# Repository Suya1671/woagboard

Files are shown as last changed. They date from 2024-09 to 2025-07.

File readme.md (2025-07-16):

# Woagboard: Bisexual egg edition
_name chosen by popular vote._

Woagboard

**ROUND 3** This is the third hardware revision of the Woagboard keyboard. It's a 5x3 split ergonomic keyboard with 3 thumb keys on each half (36 keys total), inspired by the [TOTEM](https://github.com/GEIGEIGEIST/TOTEM).

I made this keyboard for myself, and to learn PCB design in the process. With the newest iteration, I've gotten into case design (Actually properly learning CAD for once), way more annoying part selection processes, and overall a chaotic time.

# Features

Woagboard with the case opened

- 36 Keys
  - 5x3 matrix, with 3 thumb keys on each half
  - Splayed, column-staggered, ergonomic design
- Wireless, with generous space to fit a battery
  - 400mAh should last you a month
- On-board MCU
  - Nordic nRF52840, for BLE and USB-C connectivity
- Chaotic silkscreen printing
- Optional nice!view display mounting point
- RMK and ZMK firmware support

## The case
Woagboard Case

The case is designed to be 3D printed, with a focus on being thin, minimalistic, and clean. It features cutouts for all the necessary ports and buttons, and has a dedicated space for the nice!view display on the left half.
It also features cutouts for [Tenting Feet](https://www.aliexpress.com/item/1005005605228469.html) that make the keyboard way more comfy to use.

## The PCB

Woagboard PCB

Silly, chaotic, yet somehow functional. The PCB is as small as the layout allows it to be, featuring an on-board Ebyte E73-2G4M08S1C module for wireless connectivity (Powered by the Nordic nRF52840), a BQ24075RGT battery charger (Which allows you to charge the keyboard while it's running. Such a revolutionary feature), and a 32.768kHz crystal for deep sleep functionality.

It also has really chaotic silkscreening. We stay silly.

Woagboard PCB Silkscreen

### Schematic

Woagboard Schematic
:3

# BOM
This is the Bill of Materials (BOM) for 1 Woagboard (2 halves). This is why certain quanitites are doubled, as the board is two halves using the same PCB and components.
| Component | Designator on PCB/Usage | Supplier | Supplier URL | Quantity |
| --- | --- | --- | --- | --- |
| Woagboard PCB | Placed in case | JLCPCB | See pcb/jlcpcb for production files | 2 |
| Ebyte E73-2G4M08S1C MCU* | U1 | LCSC | <https://lcsc.com/product-detail/C356849.html> | 2 |
| TI BQ24075RGT Battery Charger | U2 | LCSC | <https://lcsc.com/product-detail/C15464.html> | 2 |
| Onsemi SRV05-4 ESD Protection | U3 | LCSC | <https://lcsc.com/product-detail/C2836319.html> | 2 |
| Korean Hroparts Elec TYPE-C-31-M-12 | J1 | LCSC | <https://lcsc.com/product-detail/C165948.html> | 2 |
| 1x6 Vertical Pin header | J2 | LCSC | <https://lcsc.com/product-detail/C706869.html> | 2 |
| Panasonic EVQ-P7C01P push button | PWR1,RST1 | LCSC | <https://lcsc.com/product-detail/C388883.html> | 4 |
| Yellow LED | LED1 | LCSC | <https://lcsc.com/product-detail/C2296.html> | 2 |
| Green LED | LED2 | LCSC | <https://lcsc.com/product-detail/C2297.html> | 2 |
| 4.7uF Capacitor | C2,C3,C4,C5 | LCSC | <https://lcsc.com/product-detail/C23733.html> | 8 |
| 1uF Capacitor | C1,C6 | LCSC | <https://lcsc.com/product-detail/C52923.html> | 4 |
| 18pF Capacitor | C7,C8 | LCSC | <https://lcsc.com/product-detail/C1549.html> | 4 |
| 47kΩ Resistor | R4 | LCSC | <https://lcsc.com/product-detail/C25792.html> | 2 |
| 10kΩ Resistor | R7 | LCSC | <https://lcsc.com/product-detail/C25744.html> | 2 |
| 5.1kΩ Resistor | R1,R2 | LCSC | <https://lcsc.com/product-detail/C25905.html> | 4 |
| 3.9kΩ Resistor | R6 | LCSC | <https://lcsc.com/product-detail/C23018.html> | 2 |
| 270Ω Resistor | R3,R5,R8 | LCSC | <https://lcsc.com/product-detail/C25867.html> | 6 |
| 750 mA fuse | F1 | LCSC | <https://lcsc.com/product-detail/C2687878.html> | 2 |
| 32.768kHz Crystal | Y1 | LCSC | <https://lcsc.com/product-detail/C32346.html> | 2 |
| Murata Electronics BLM15PX121SN1D Ferrite Bead | L1 | LCSC | <https://lcsc.com/product-detail/C88970.html> | 2 |
| 10uH Inductor | L2 | LCSC | <https://lcsc.com/product-detail/C223249.html> | 2 |
| Kailh PG1350 Choc Hotswap Sockets | SW1-SW18 | AliExpress** | <https://www.aliexpress.com/item/1005004290562374.html> | 30 x 2 (36 used) |
| Woagboard Case | Surrounds PCB. Connected Via M2 screws | 3D Printed | See case for models | 1x Left, 1x Right |
| M2x10 Countersunk Screws | H1 (Mounting Point) | JKM | <https://jkm.co.za/product/m2x10-csk-galv-m-screw-bos/> | 2 |
| M2x12 Countersunk Screws | H2, H3 (Mounting Points) | JKM | <https://jkm.co.za/product/m2x12-csk-galv-m-screw-bos/> | 4 |
| M2 Brass Heat inserts | H1, H2, H3 (Mounting Points) | AliExpress | <https://www.aliexpress.com/item/32890237459.html> | 50 x 1 (6 M2 inserts used) |
| Laptop Tenting Feet | Attached to case | AliExpress** | <https://www.aliexpress.com/item/1005005605228469.html> | 2 x 2 |
| Choc switches | SW1-SW18 (Connected via hotswap) | AliExpress | <https://www.aliexpress.com/item/1005005883472162.html> | 30 x 2 (36 used) |
| Choc keycaps | SW1-SW18 (Connected via switch) | AliExpress | <https://www.aliexpress.com/item/1005004558099208.html> | 50 x 1 (36 used) |
| nice!view | J4 (Wired up with wires. nice!view placed in case) | Typeractive  | <https://typeractive.xyz/products/nice-view> | 1 |

Notes:

- \* Alternativelty, the Ebyte E73-2G4M08S1CX can be used for a UFL connector, requiring an external antenna. Both options annoyingly got moved to standard assembly only while I was making this design, increasing costs dramatically (~$60 -> ~$100). I've contacted JLCPCB about this, and hopefully I can get it back on economic assembly for anybody else trying to make this board.
- ** Typeractive also has these. If you're in the US, might be better to buy from them instead.
- I already have switches and keycaps, so I don't need to purchase them.
- I am not purchasing the nice!view for the fact that I'm out of budget if I do. Thanks JLCPCB.

# Copyright notice
The Woagboard is not affiliated with New Blood Interactive, Tour De Pizza, or any other IPs referenced on the design.
I just like ULTRAKILL, Pizza Tower, etc.

- Keycap model taken from https://www.thingiverse.com/thing:4564253 (CC BY-NC)
- Keyswitch model taken from https://github.com/kiswitch/kiswitch
- nice!view model taken from https://www.printables.com/model/1114611-niceview-oled/files (CC BY-NC)
- Neocats from https://volpeon.ink/emojis/neocat/ (CC-BY-NC-SA-4.0)
- Neofox from https://volpeon.ink/emojis/neofox/ (CC-BY-NC-SA-4.0)
- Neodog from https://git.gay/moonrabbits/neodog/src/branch/main/neodog/neodog.png (CC-BY-NC-SA-4.0)
- Neorat from https://emoji-repo.absturztau.be/repo/neorat.zip (CC-BY-NC-SA-4.0)
- Neobread from https://github.com/olivvybee/emojis/blob/main/neobread/neobread.svg (CC-BY-NC-SA-4.0)
- Neobot from https://github.com/SymTrkl/emoji/blob/main/webres/neobot/neobot.png (CC-BY-NC-SA-4.0)
- Monadic Cat's mask from https://www.catmonad.xyz/pfp.html (CC-BY-SA-4.0)

The board's actual license is the CERN Open Hardware License v1.2. See the [license file](./license.md) for more information.

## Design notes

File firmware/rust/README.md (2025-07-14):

# Woagboard Firmware: RMK

RMK is a feature-rich and easy-to-use keyboard firmware, which has VIAL support and is incredibly power efficient.

The default layout is the wobbler's personal layout, using dust and a bunch of fancy features.
I'll eventually probably maybe make the default QWERTY and less opinionated.

## uf2 support

If you’re using the Adafruit_nRF52_Bootloader (Recommended for the Woagboard), you’re in luck! This bootloader supports the .uf2 firmware format, which eliminates the need for a debugging probe to flash your firmware. RMK uses the `cargo-make` tool to generate .uf2 firmware, with the generation process defined in the `Makefile.toml`.

Follow these steps to generate and flash the .uf2 firmware with RMK:

1. Get `cargo-make` tool:
   ```shell
   cargo install --force cargo-make
   ```
2. Compile RMK and generates .uf2 firmware:
   ```shell
   cargo make uf2 --release
   ```
3. Flash
   - For each half:
    - Put your half into bootloader mode. This can be done by quickly double tapping the reset button.
    - A USB drive will appear on your computer under the name "WOAGBOARD".
    - Drag and drop the generated .uf2 firmware file onto the USB drive. The RMK firmware will be automatically flashed onto the Woagboard.

### Additional notes

RMK defaults to USB-priority mode if a USB cable is connected. After flashing, remember to disconnect the USB cable, or [switch to BLE-priority mode](https://rmk.rs/docs/features/wireless.html#multiple-profile-support) by pressing User7(Switch Output) key.

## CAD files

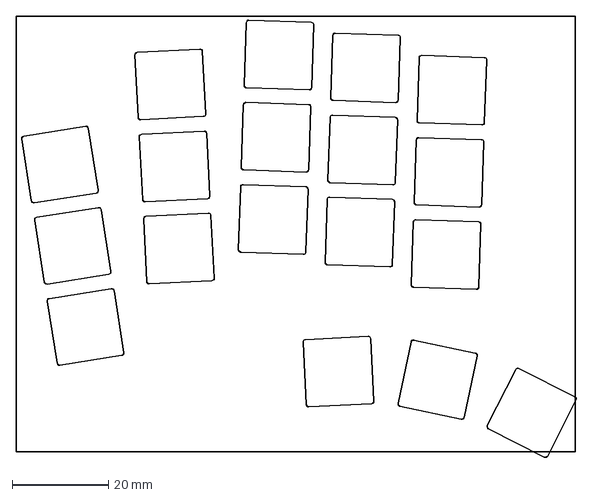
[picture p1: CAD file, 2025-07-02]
case/plate.dxf
116.2 x 91.6 mm

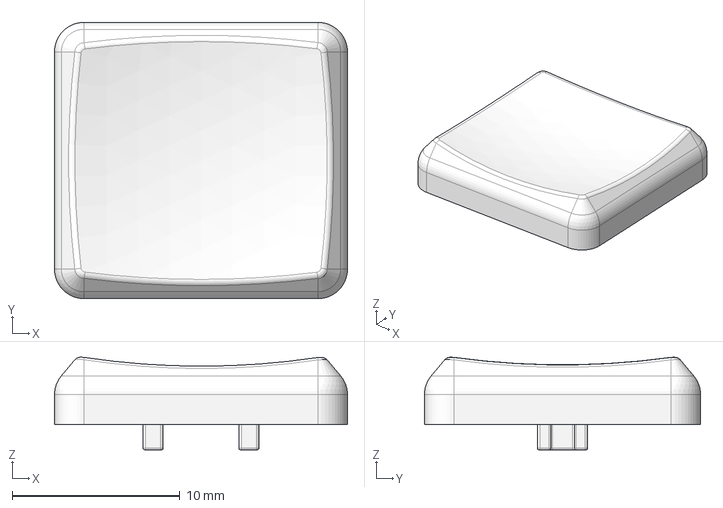
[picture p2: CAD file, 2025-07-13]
pcb/Models/MBK_Keycap_-_1u.step
17.4 x 16.4 x 5.52 mm

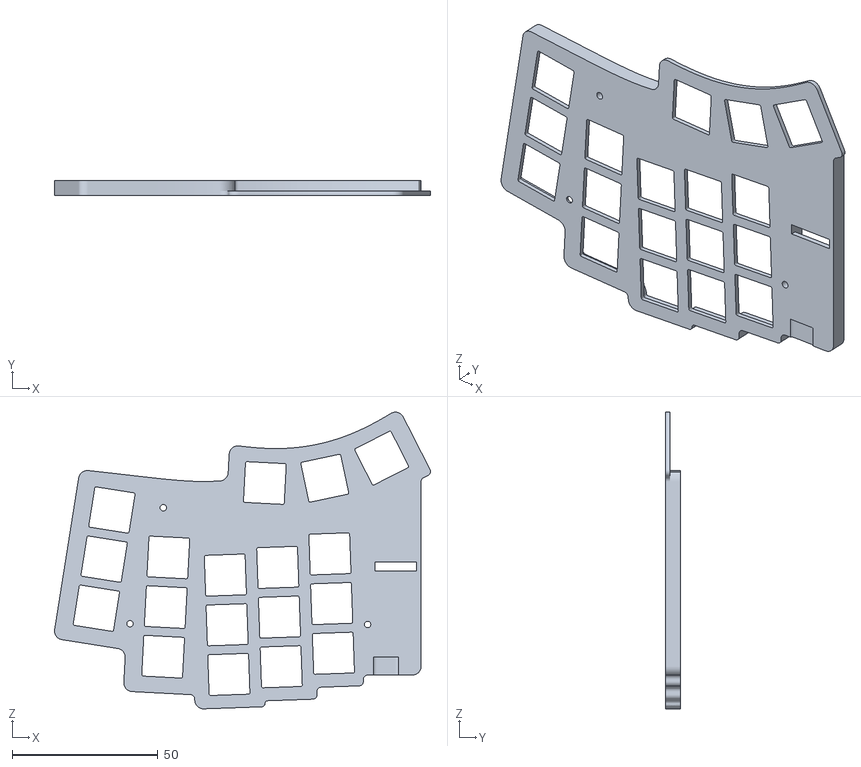
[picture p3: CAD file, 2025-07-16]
production/Top Left.stl
129.0 x 5.00 x 101.8

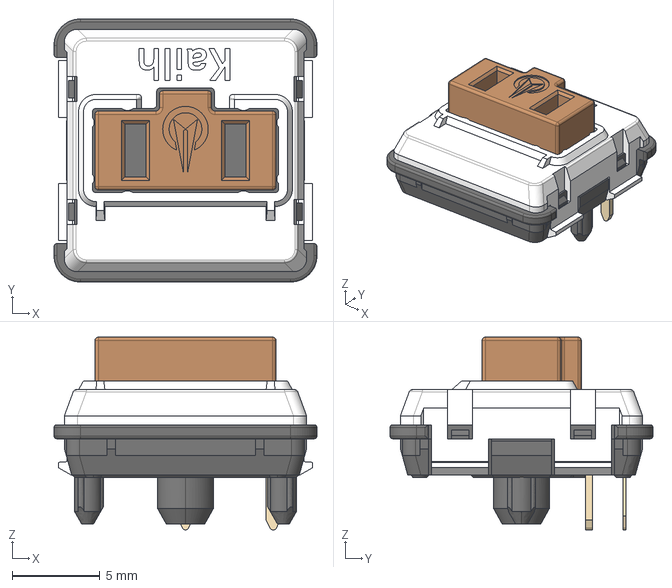
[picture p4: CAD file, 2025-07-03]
pcb/Models/SW_Kailh_Choc_V1.stp
15.0 x 15.0 x 11.0 mm

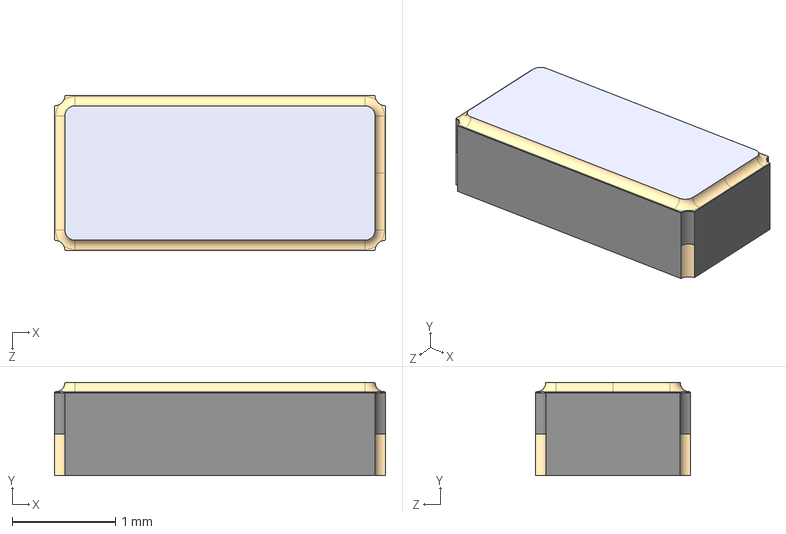
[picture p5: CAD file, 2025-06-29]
pcb/Models/Q13FC13500004.STEP
3.20 x 0.9 x 1.50 mm

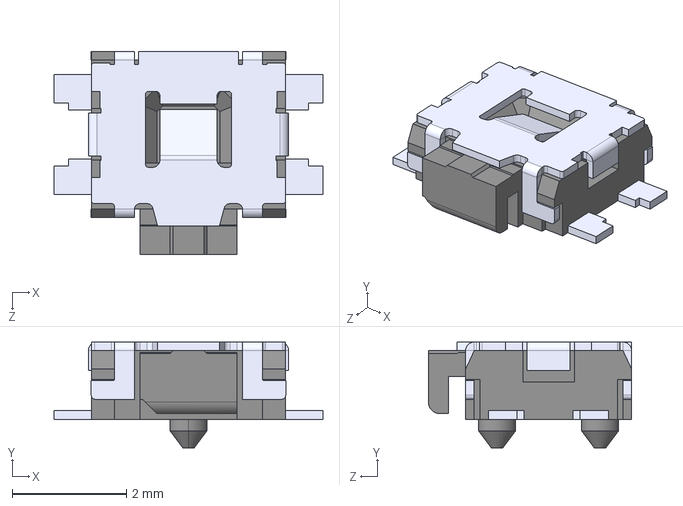
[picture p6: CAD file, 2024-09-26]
pcb/Models/EVQP7C01P--3DModel-STEP-269445.STEP
4.70 x 1.85 x 3.55 mm

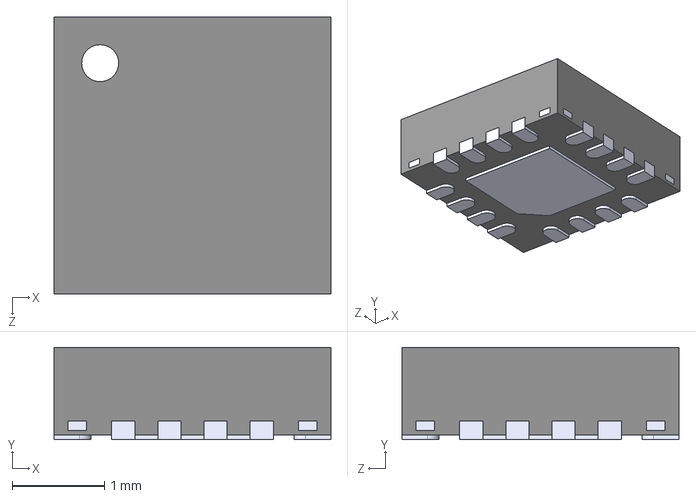
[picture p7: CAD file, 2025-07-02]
pcb/Models/BQ24075.STEP
3.00 x 1.00 x 3.00 mm

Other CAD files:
production/Top Right.stl

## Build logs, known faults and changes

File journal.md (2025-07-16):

---
title: "Woagboard V3"
author: "Suya"
description: "My woagboard keyboard idea combined with a modified version of the yeagpad's layout."
created_at: "2025-06-28"
---

**Total hours spent: ~50 hours**

# June 26th

I started working on getting the project setup. I removed the old files, updated the Ergogen code, and recreated the KiCAD project

Also, I use Ergogen to just [place the switches](https://github.com/adamws/kicad-kbplacer) on the PCB using a KiCAD. No actual PCB is generated by it.

## Schematic work

I'm mostly taking ideas and design from the amazing [ZMK Design guide](https://github.com/ebastler/zmk-designguide) and the work I've done for quiz-sys. I plan to re-use most of the components I did for the [Woagboard v0.2](https://github.com/suyashsurya/woagboard/tree/v0.2), but with everything completely re-done.

Fun thing for the BQ24075 is that I can just... Completely ignore the SYSOFF pin. ZMK has a soft-off mode that allows me to turn off and on the keyboard
through a button, so I'll be adding that to my design.

I decided to move a bunch of components in-line rather than putting them on a separate bit of the schematic, such as the low-power oscillator and DCCH inductor.
The design on the design guide confused me for the first time, since it didn't make sense to me. This makes it way clearer to my silly brain.

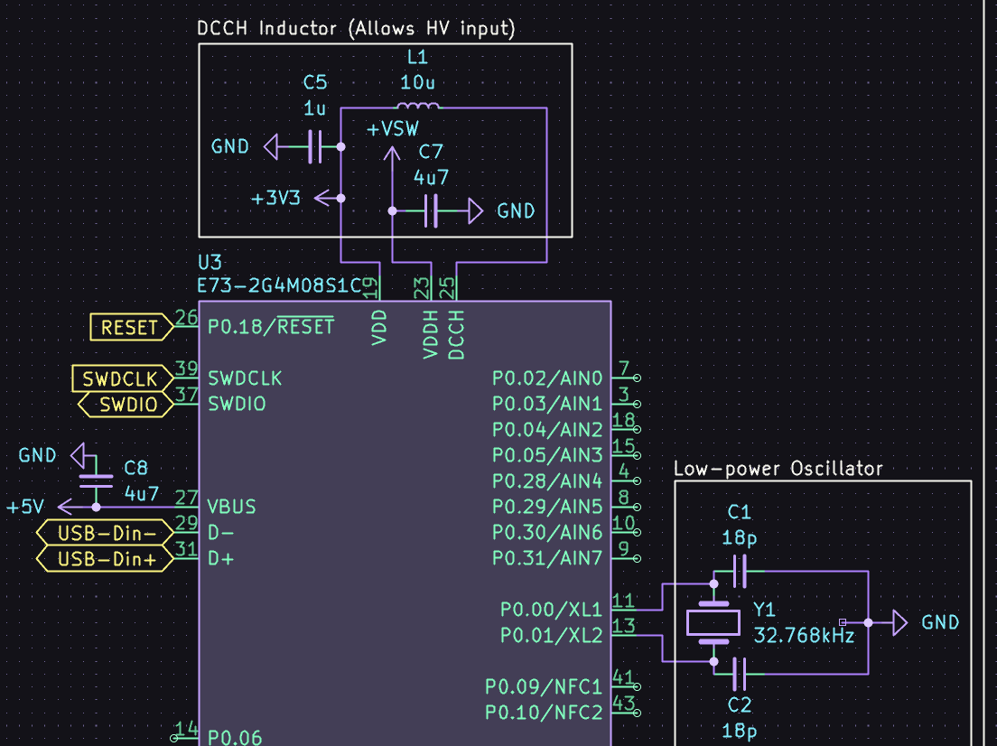
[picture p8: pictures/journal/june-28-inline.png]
A part of the woagboard's MCU schematic

_Huh. That's a lot clearer than the decoupling capacitors being like 50 spaces away._

Not sure how I feel about the DCCH loop, but it works for now.

Also for the first time ever: I filled out the info block
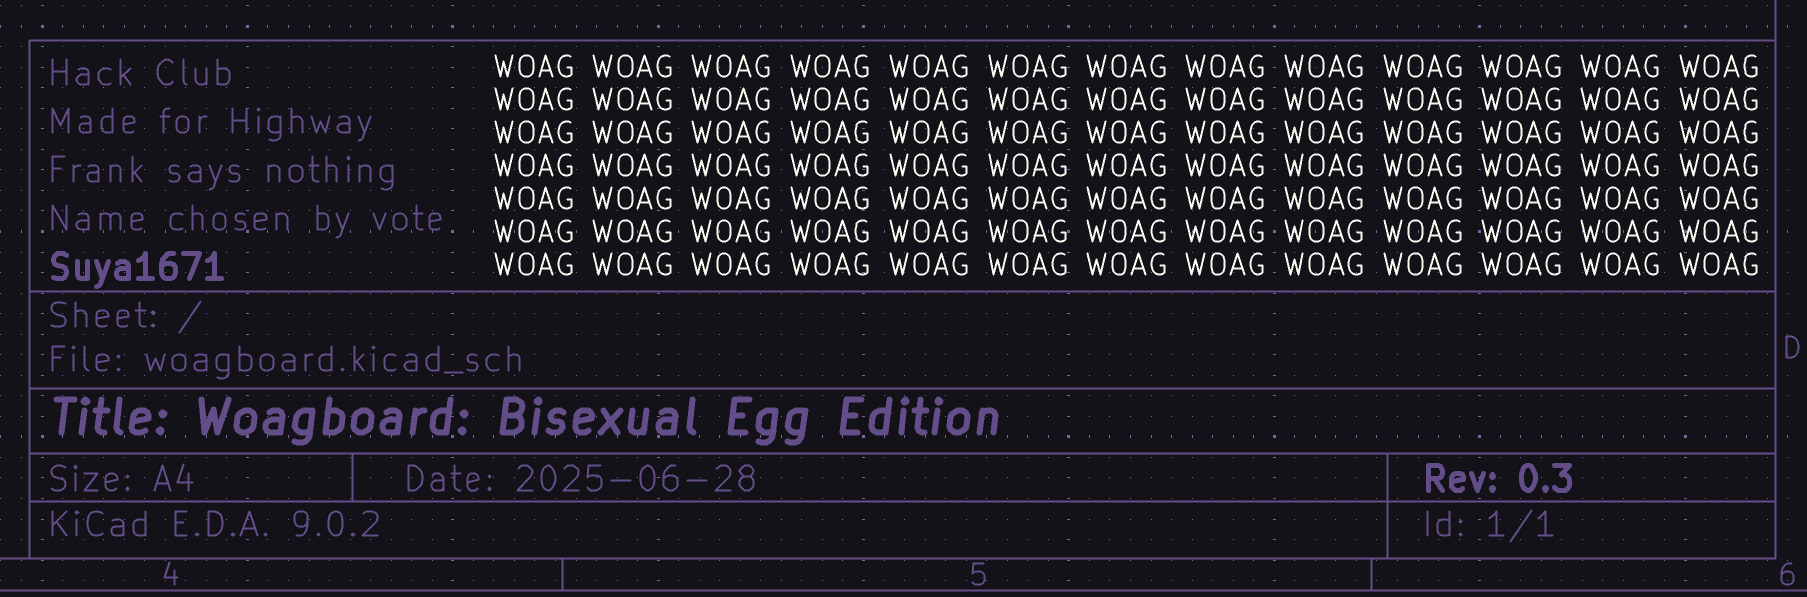
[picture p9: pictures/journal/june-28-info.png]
the woagboard's schematic's info block

_WOAG_

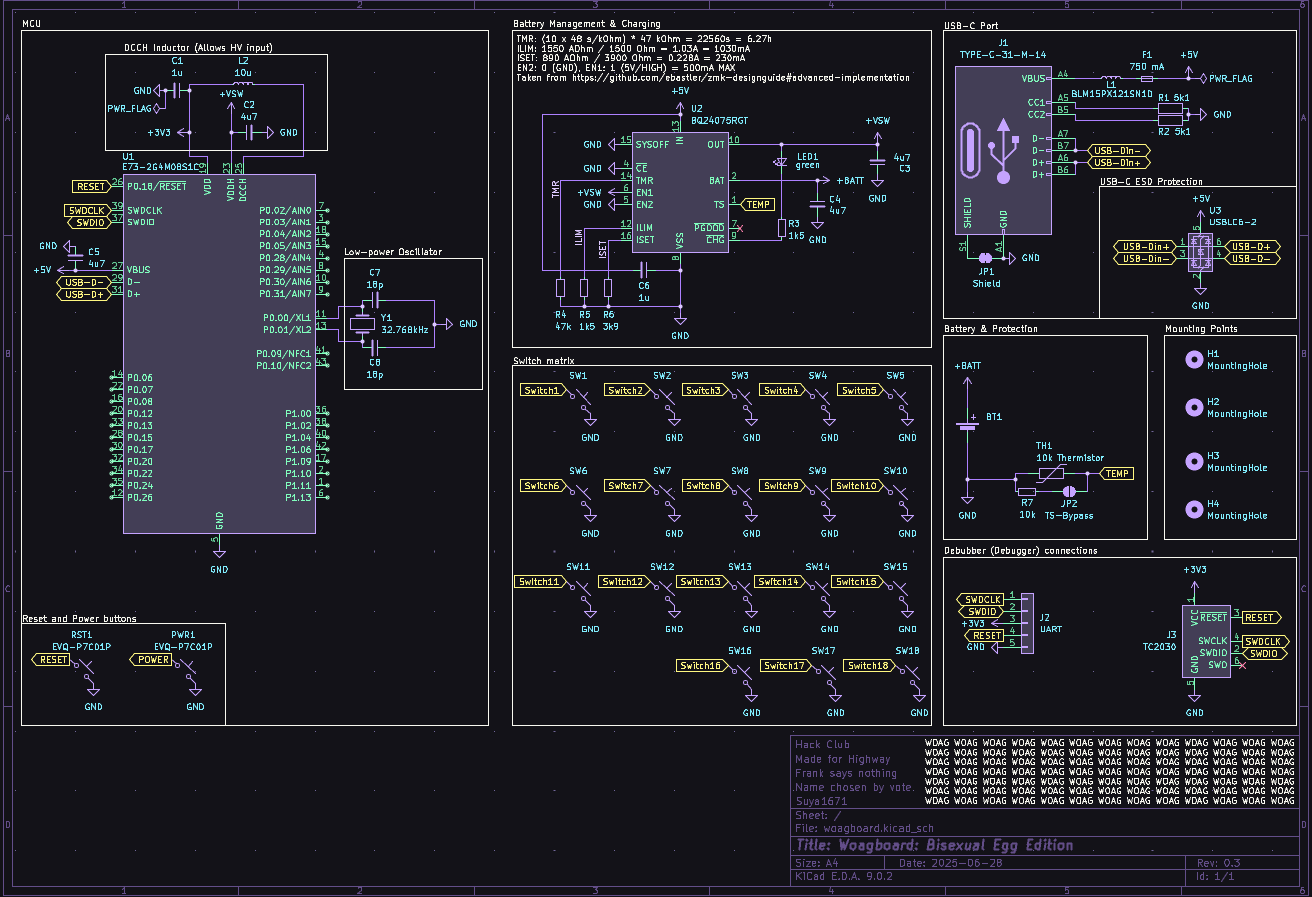
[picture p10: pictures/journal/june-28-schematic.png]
the woagboard's schematic

_I'm pretty proud of this ngl_

I might add ARGB later, depending on if I'm feeling up for the absolute routing nightmare that it is going to be

**Total time spent: 3 hours**

Next up: PCB footprints and board outline

# June 27th

Started early today at ~11:10. Worked for... the entire day.

Did a check over my schematic and started working on footprints. I redid my old Panasonic EVQP7C01P footprint and made a new crystal oscillator footprint.

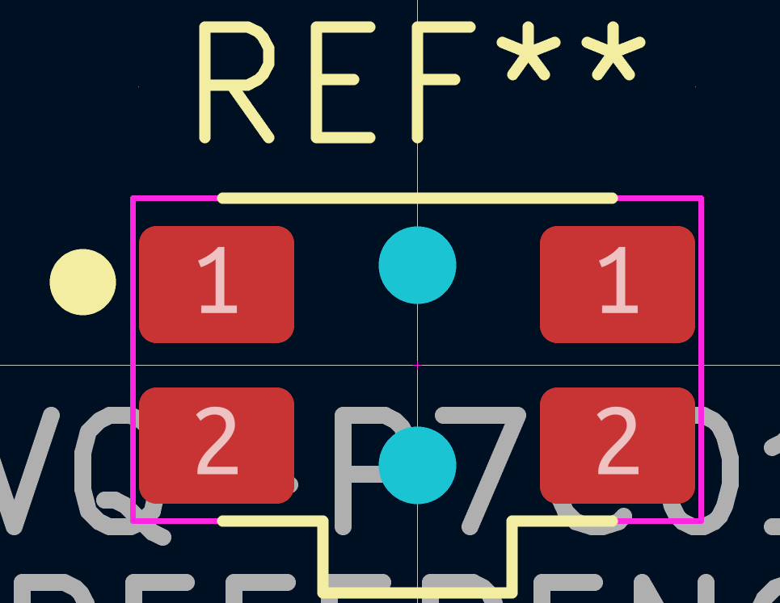
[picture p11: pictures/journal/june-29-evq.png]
EVQP7C01P footprint

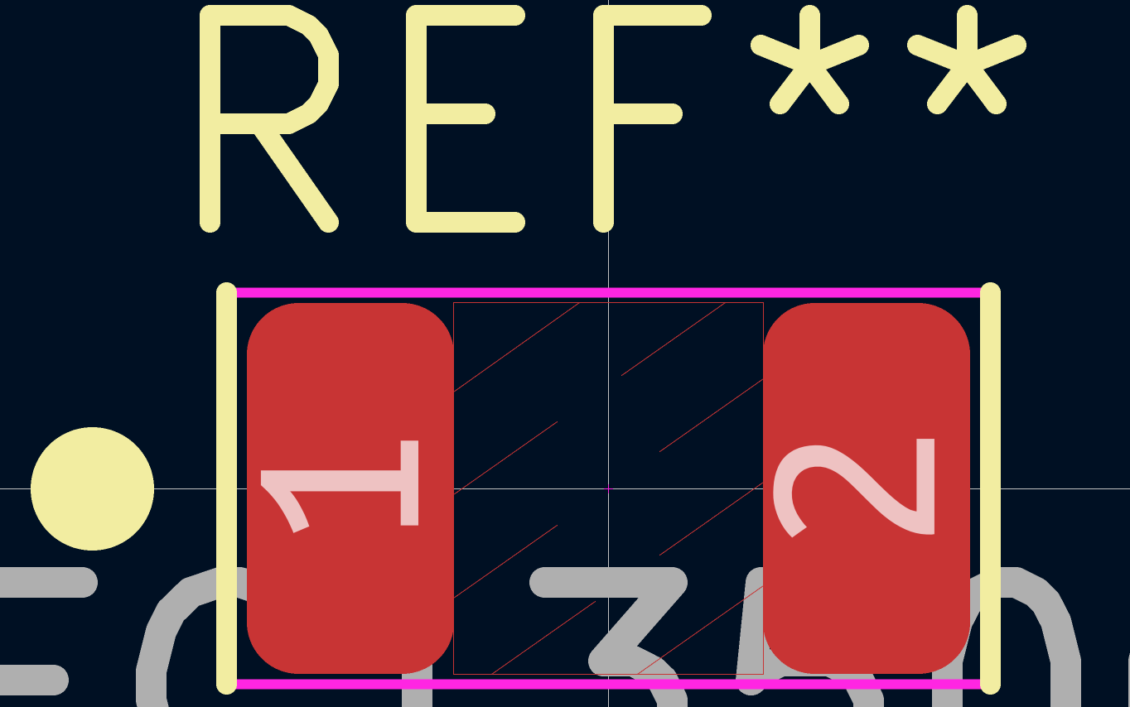
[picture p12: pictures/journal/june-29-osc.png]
Crystal Oscillator Footprint

_Algebra go brr_

I took my Choc V1 Reversible PCB footprint from the Yeagboard. I am not remaking that. It genuinely took me 2 days to get that working when I did it.
I might modify it to add ARGB, but I'm unsure, especially considering battery life implications

Anyways: I started off with this mess for the PCB:
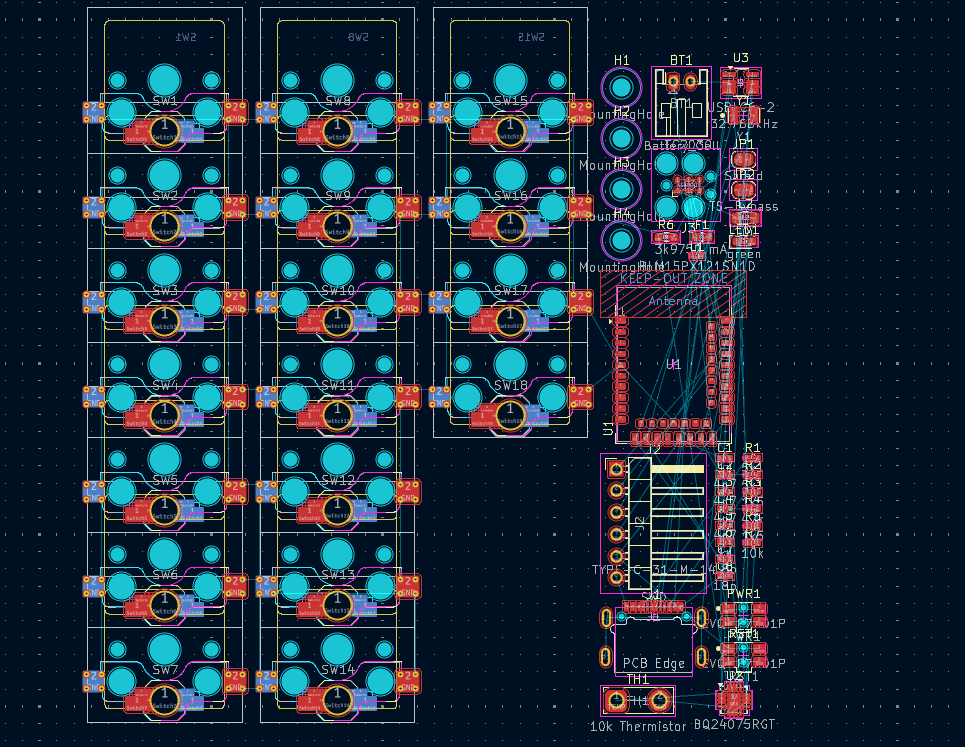
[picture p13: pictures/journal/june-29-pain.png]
A grid of all PCB components/footprints the woagboard uses

_Lettuce begin the train of pain_

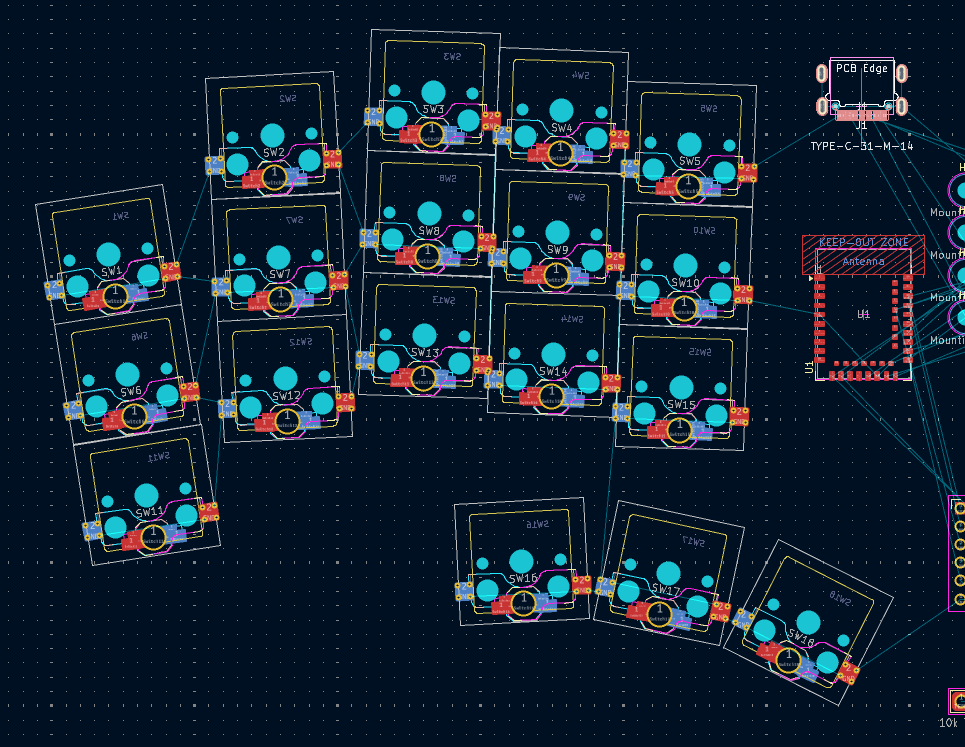
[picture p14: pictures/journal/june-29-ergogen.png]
Keys in the correct position

_...And this is the only reason I used ergogen_

I initially planned to have the MCU antenna face the right side of the board, but then I realised that, for my insanely tight routing plans, I would not have enough space.
Thus, compromise: the MCU faces downwards. This is going to be fun to route later.

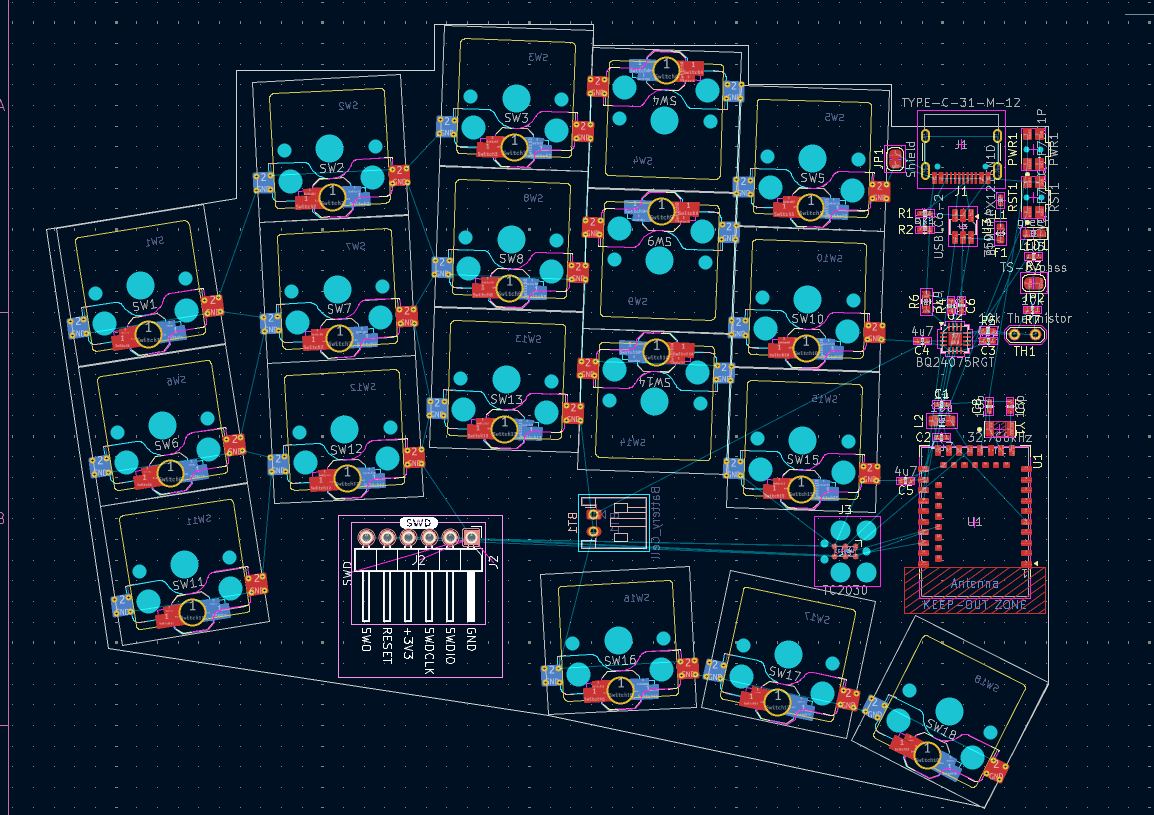
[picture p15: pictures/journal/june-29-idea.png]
WIP of final component positions

_Oh no..._

And then I kinda just... got into a flow. The world didn't exist. Just me, KiCAD, and a hell of a lot of routing to get done.
It is now... ~18:00 When I wrote this. It's been like 4 hours of continuous routing. I do not like routing because it feels
like you spent so much time but got nothing done. Bleh.

Anyways here's some fun things I've routed:

Tag Connect TC2030 "connector" (AKA just a bunch of pads and holes)
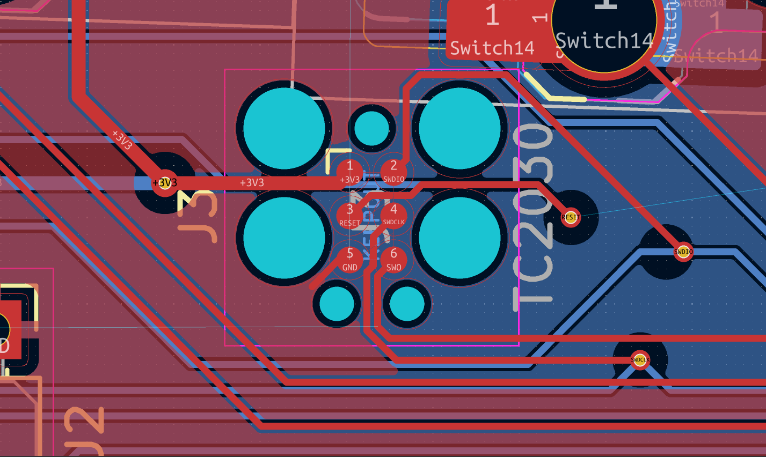
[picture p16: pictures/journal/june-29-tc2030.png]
Routed TC2030 connector

_Forgive me JLCPCB, for I have sinned_

The Nrf52840 DC/DC buck converter
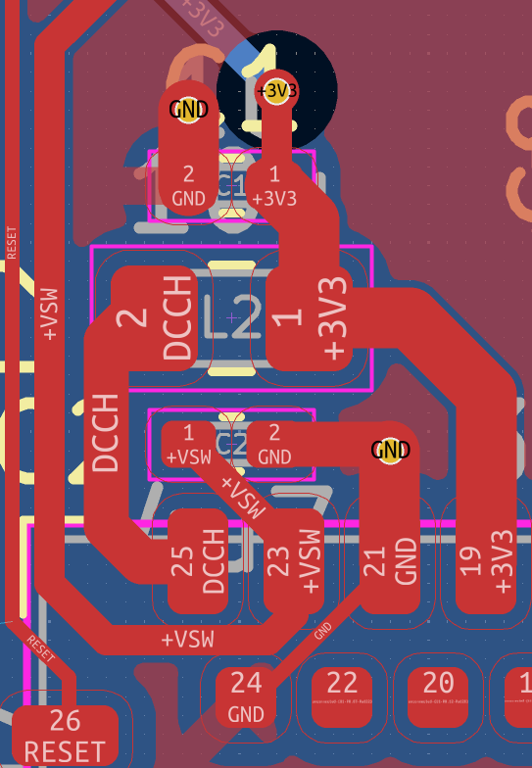
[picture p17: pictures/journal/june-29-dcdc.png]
Routed DC/DC voltage loop

_Honestly, this was pretty fun to try optimise_

Update: it's now 10PM. After quite a few delays and things inbetween, first routing pass is done! This part took me the longest:
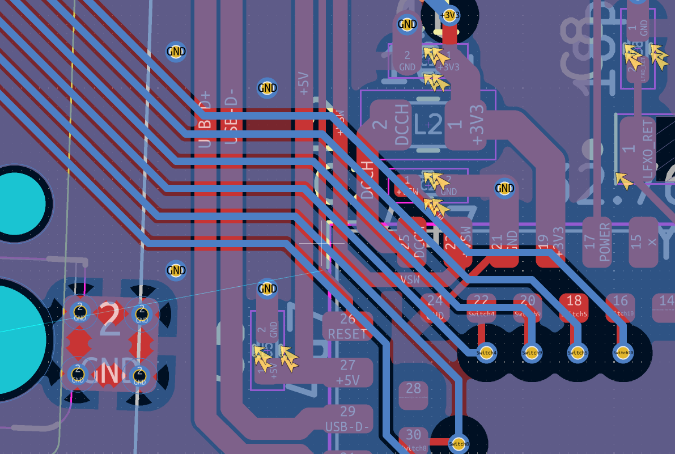
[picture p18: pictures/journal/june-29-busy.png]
Very busy PCB routing

_Just wrapping my head around what I was viewing was half the battle_

Anyways I'm tired and it's time to sleep

**Total hours spent: 7 hours** (yep...)

# June 30th

I realised I forgot to add a status LED. Oops.
...I also forgot to use wakatime-kicad. Oops x2 combo.

Turns out, JLCPCB only has 6 options for basic LEDs. Kinda limit colour selection :c.

I mostly worked on the board outline today. Turns out, KiCAD now has a decent bezier curve tool. It also has decent edge rounding.
I no longer need FreeCAD and 5000 constraints to make a decent board outline anymore, which is really nice.

I also decided to replace the USBLC6 with an SRV05-4. It's recommended by the zmk designguide and doesn't require an extra capacitor (which I forgot about for the USBLC6), which is nice.

I also finally added in more 3D models for the keyswitches and caps, and now plan to make a case for it in FreeCAD. Time to see how that goes.
Finally for today, a blender render of the board.

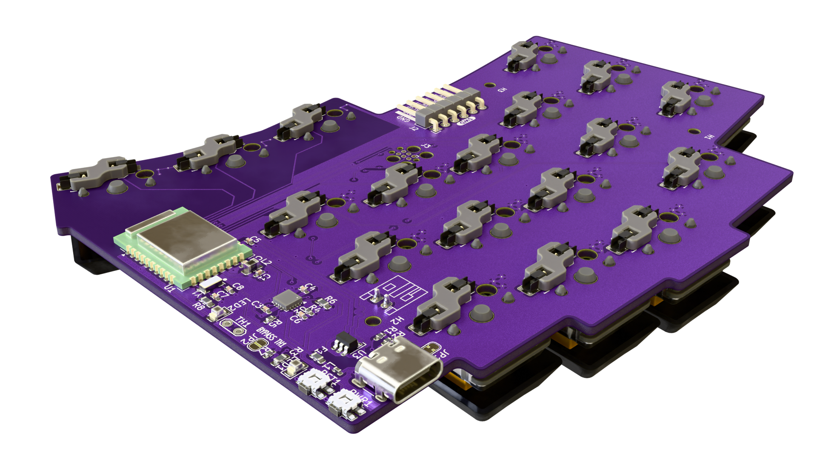
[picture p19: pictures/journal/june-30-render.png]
A render of one half of the woagboard

_[pcb2blender](https://github.com/30350n/pcb2blender) my beloved_

Next up: Make a case for the board in FreeCAD

**Total hours spent: 4 hours**

# July 2nd

I have decided I want a screen on the woagboard. PCB update time.

I've decided to go with a nice!view, mostly because it's a standard size (so I can attack a cheaper OLED if I wanted to), and should be *fairly* simple to add to the board.

Update: The screen won't fit. It intersects with the MCU traces badly :c

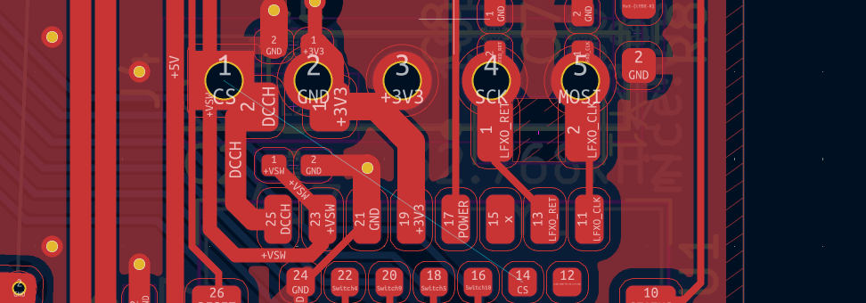
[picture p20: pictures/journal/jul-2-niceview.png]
The nice!view header footprint intersecting various components

_Yeah that ain't working out, chief._

Idea 2: place pads and just wire up the screen

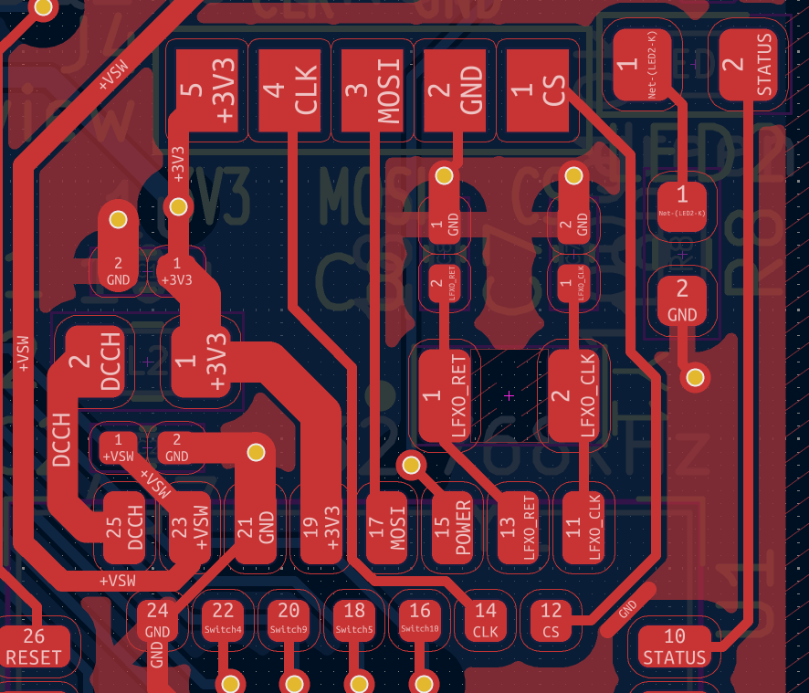
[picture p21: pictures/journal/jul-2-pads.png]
The newly added pads for wiring the nice!view later

_Well... It worked, but it was painful_

I also decided to do a tiny bit of work on the silkscreen. Thus: info block

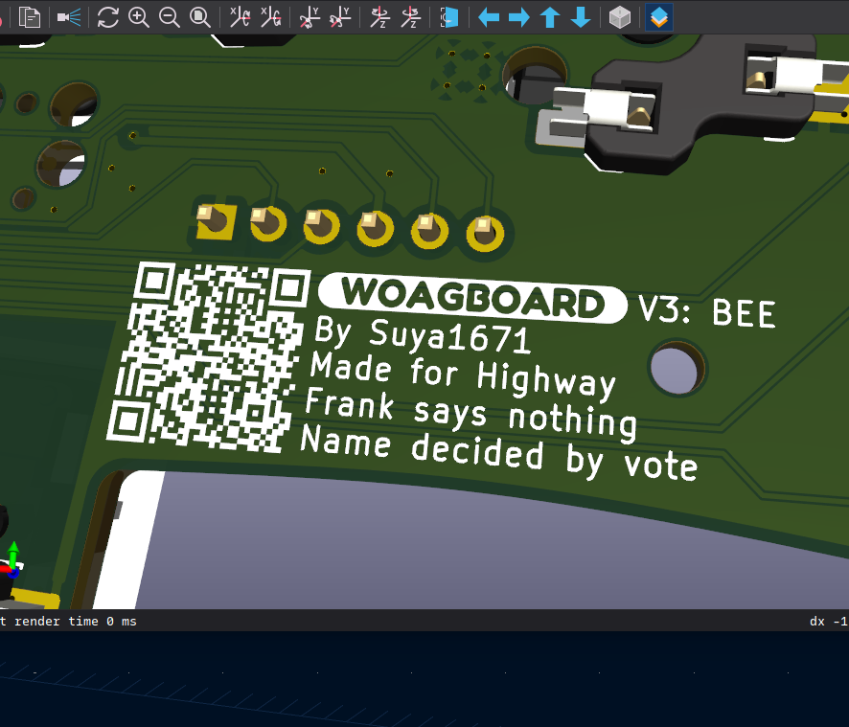
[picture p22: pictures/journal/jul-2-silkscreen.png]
Silkscreen containing information about the board

_BEEEEEEEEEEEEEEEEEEEEEEEE_

**Total hours spent: 2 hours**

# July 3rd-9th

So uh, I was on holiday for a week. In that time I worked on the hardware design a _lot._
I wasn't able to journal much (I was), so I hope a post-review is adequate.

Anyways: I did not use FreeCAD. That thing scares me still. Instead, I used Fusion 360. This also has the handy benefit of automatically keeping track of revisions, and boy do I have a lot of them. For the timing, I have timestamps in fusion to work off of. It won't be completely accurate, but it's something to consider

## July 3rd

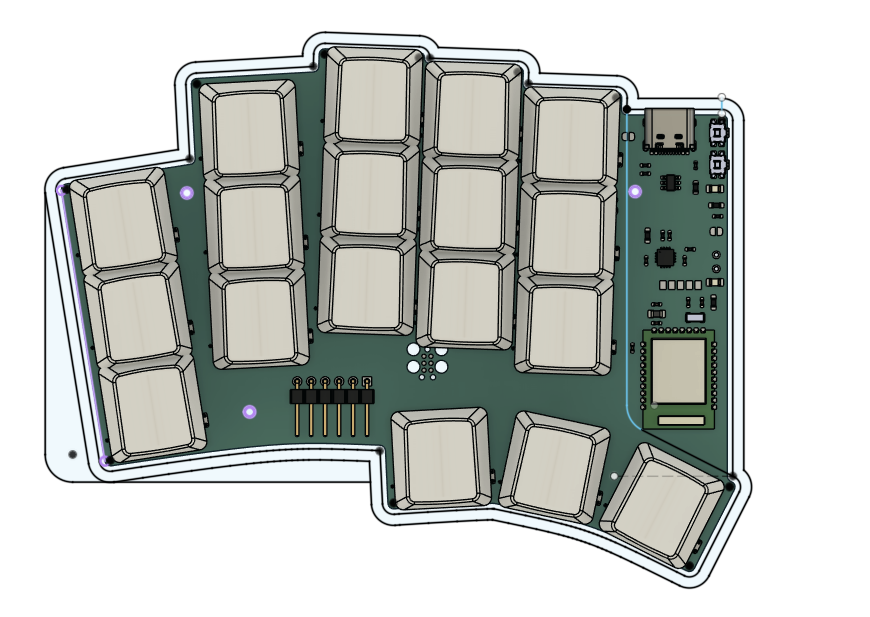
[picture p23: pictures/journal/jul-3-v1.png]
First revision of the case

_In the beninging_

I started off with making a sketch. And this is the main issue honestly: I only used 2 sketches for most of the design phase, constantly editing it. This lead to some... _interesting_ sketch intersections later on.

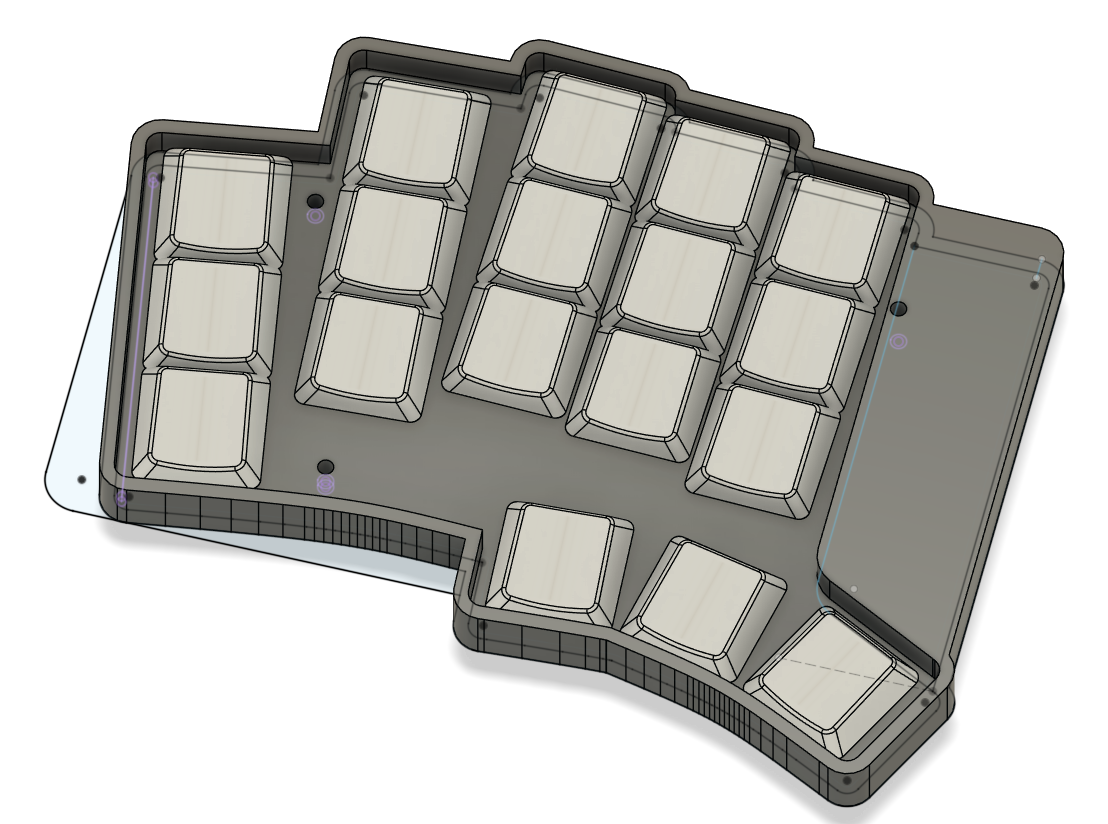
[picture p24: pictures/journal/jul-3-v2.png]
2nd revision of the case and sketch

_Woah! Geometry!_

As you can see, I settled on a design pretty fast. Most of the design iterations was making this basic idea _look good_ and _be as thin as possible_

I continued designing, making cutouts for the switches, etc. I wanted the front to look like the TOTEM: where there aren't keys, it's filled in. It's a look and style I really like. So, I was being silly and thought "hmm. What if I just fill in the areas that aren't keys manually. Turns out, that would be slow and painful due to my weird curves and angles.

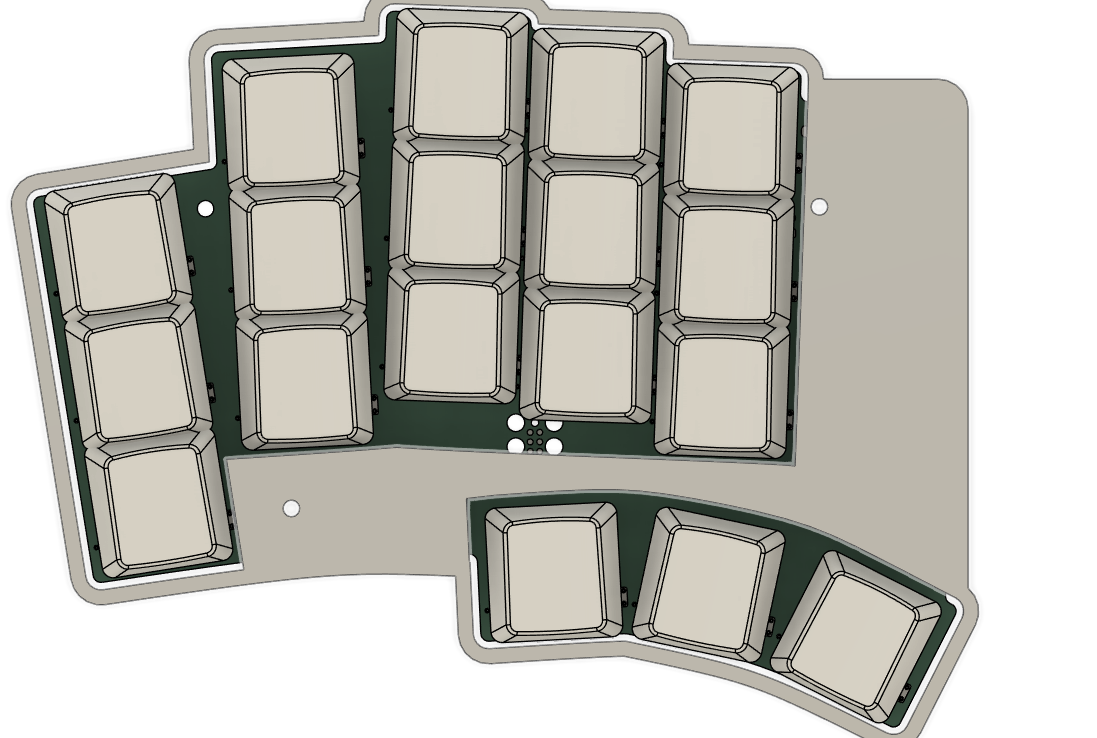
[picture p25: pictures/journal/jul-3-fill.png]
An attempt to fill in the empty spaces of the case

_Ok this ain't working chief_

Thus, a new idea that was suggested from a keyboard Discord server I'm in: simply extrude and cutout the bits where switches are. In practice, it meant I had to redo the sketch from scratch. So I did:

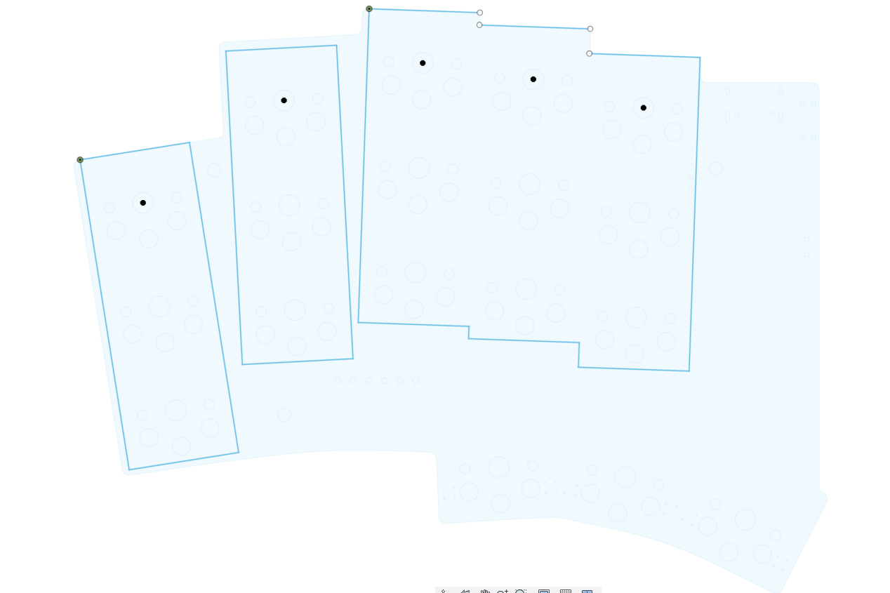
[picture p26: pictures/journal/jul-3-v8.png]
8th revision of the case sketch

_8th times the charm!_

This... Actually looks pretty good I think. So I rolled with it.

**Total hours spent: 3 hours**

## July 4th

I then went ahead and started to add more cutouts for the top case, thumb cluster, etc. and continued adjusting the design. This is the point where my brain thought "if I just steal the TOTEMs design this will surely look good!" Turns out, that was false. I reverted the decisions soon after and tried going for a more rounded and flow-y design.

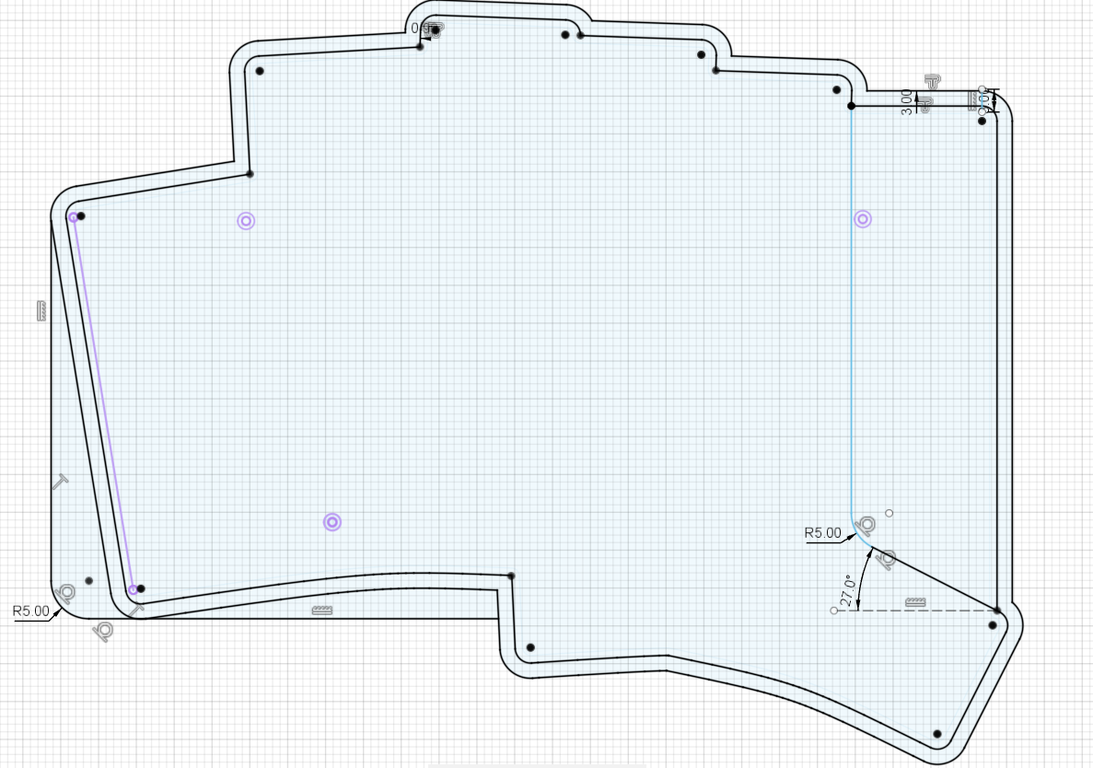
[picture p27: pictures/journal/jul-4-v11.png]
11th revision of the case sketch


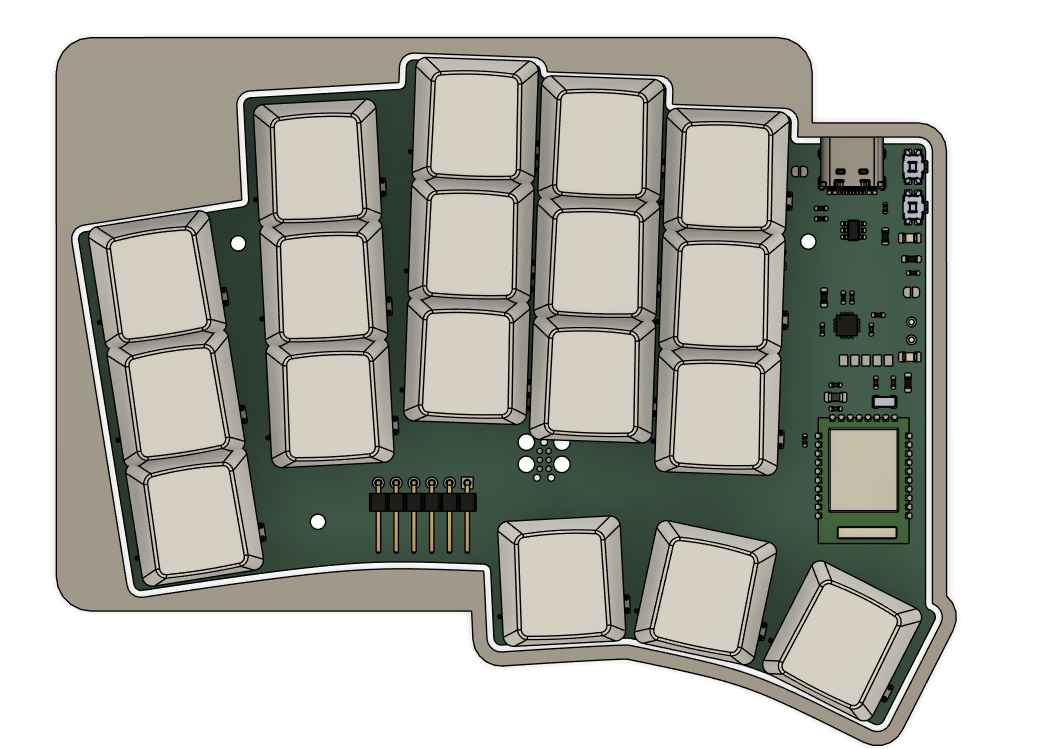
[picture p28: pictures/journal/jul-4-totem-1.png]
A design for the case based off the TOTEM

_Weird straight lines in a very curved design, but ok_

**Total hours spent: 1 hour**

## July 5th

So, heres the fun thing about the TOTEMs design (that I did keep until the end, but imo it just looks cool): The switch hotswap sockets are cutout from the bottom case. This means I need to add a sketch for every socket. The issue: the socket geometry is _weird._ This lead to uh, this:

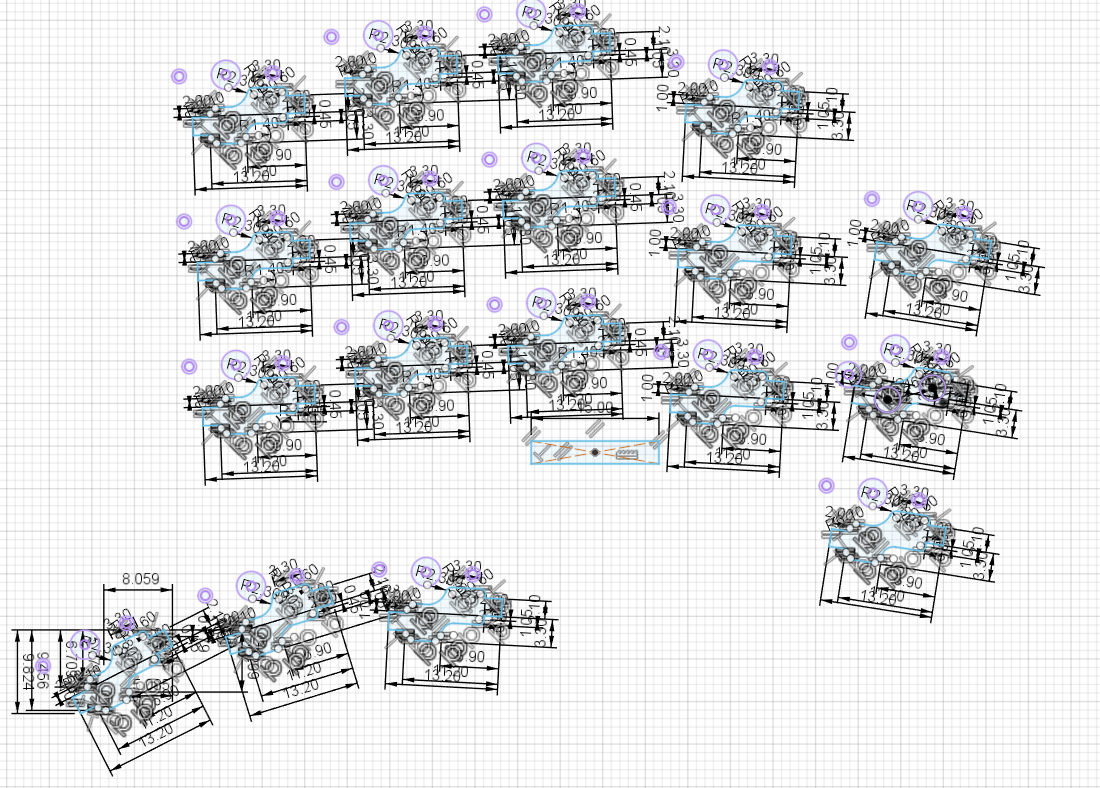
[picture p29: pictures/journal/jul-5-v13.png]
13th revision of the case sketch

_I heard you like tightly constrained sketch geometry_

This was hell to constrain. I used autoconstrain, but I had to clean it up so much that I'm not sure if it was worth it. There's also a small cutout for the debug header.

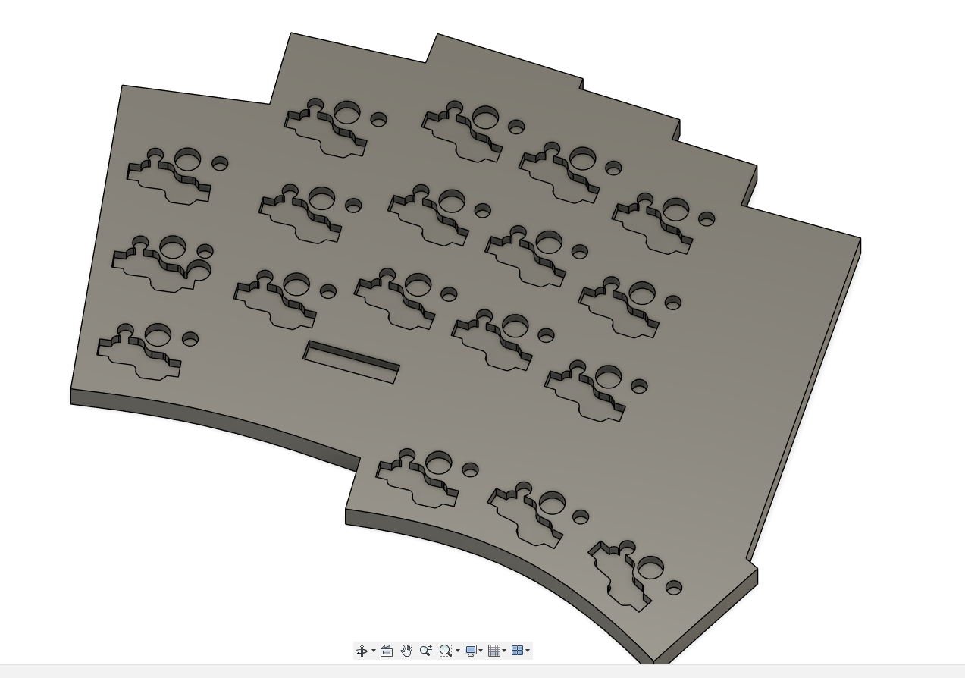
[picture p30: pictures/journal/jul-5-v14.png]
14th revision of the case

_Cutouts!_

I also made it so the cutouts were larger than the actual switches/holes as tolerance, which is why there's some intersection (it also makes it easier to 3d print to my knowledge).

I continues to clean up the top sketch, in preperation to continue working on it soon enough.

**Total hours spent: 4 hours**

## July 6th
I started finalising the top half of the case. The TOTEM goes for a design where the key plate is intergrated with the top half, giving a unique, nearly seemless look. I wanted to emulate that. After a lot of tweaking, I eventually landed on something like this:

Revision 18 of the case
_This actually looks pretty solid_

Revision 19 of the case
_"And is a snug fit"_

**Total hours spent: 2 hours**

## July 7th

I finalised the case, and started working on taking the timeline, and updating it to make 2 cases at once (for both the left and right side)

Heres some fails that happened while trying to refine this further:

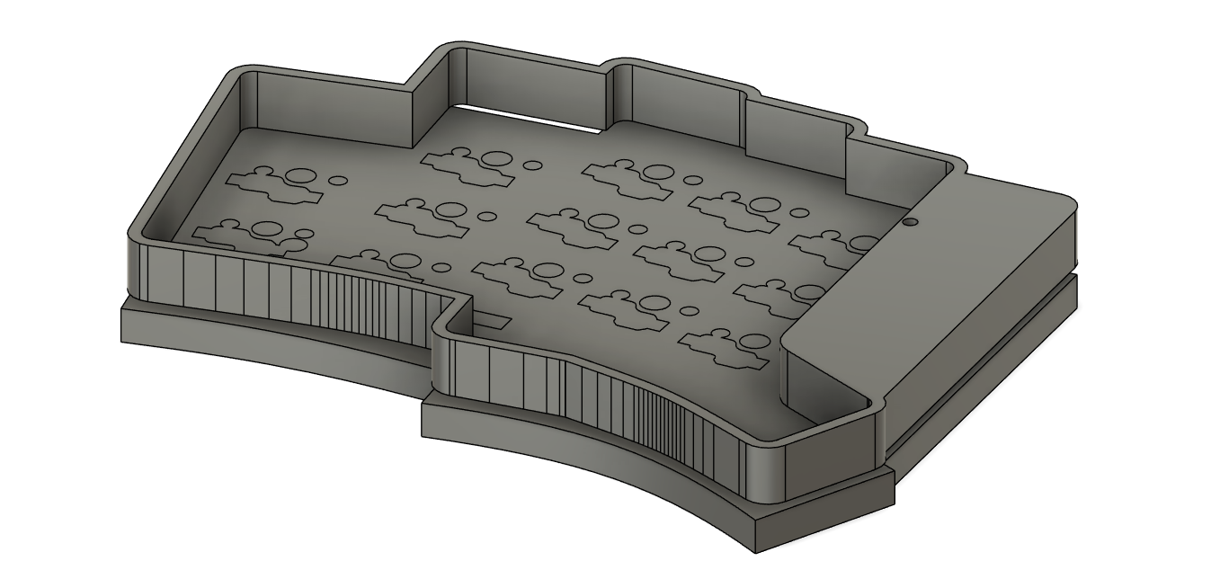
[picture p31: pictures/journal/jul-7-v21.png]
Revision 21 of the case

_Well this is just weird_

Cutouts arent' cut out, the plate just vanished, and fusion was complaining about a combine for some reason in the timeline. No idea what I was doing. I fixed it at some point though, and heres the final revision of the left case, before I started working on the dual case:

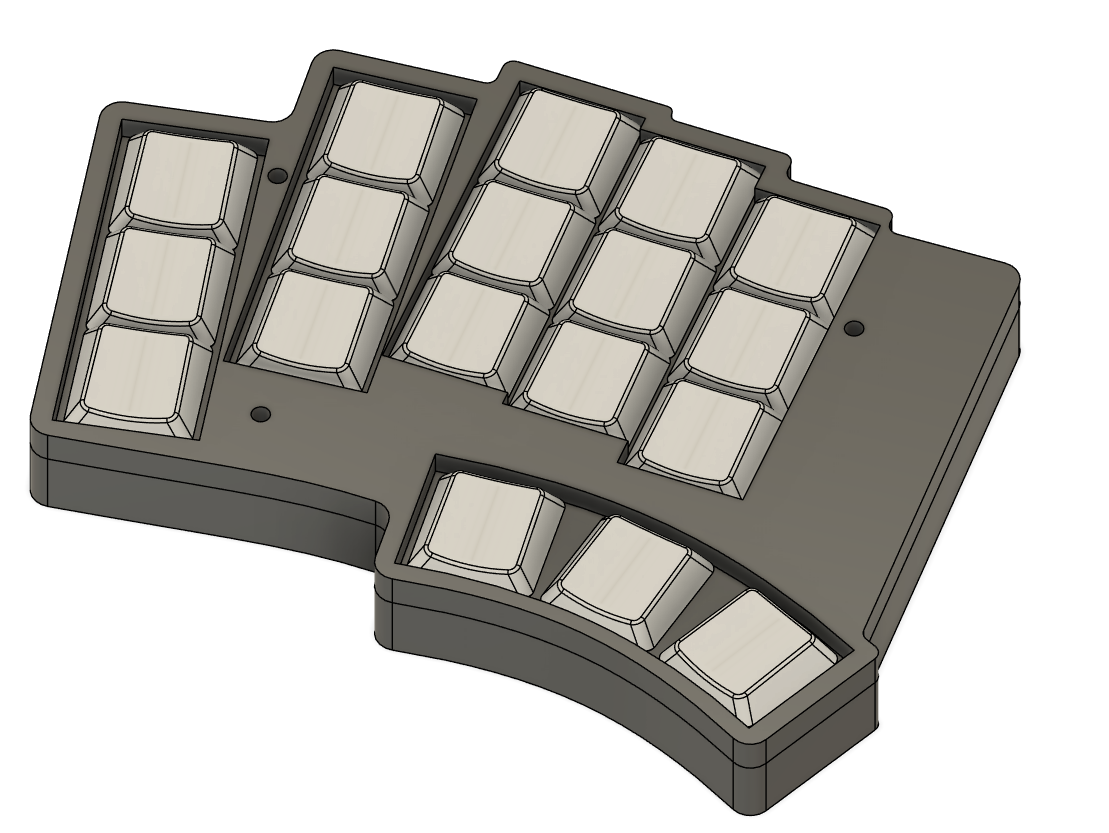
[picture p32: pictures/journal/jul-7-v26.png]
Revision 26 of the case

_Woag! (case)_

Here's a quick render (I adjusted the physical materials so it looks ok):

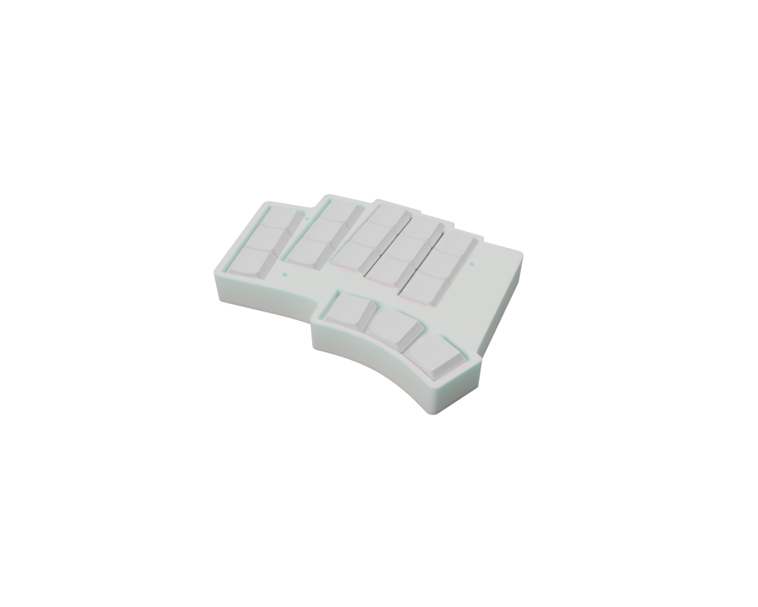
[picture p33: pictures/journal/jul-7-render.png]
Render of the case

_Fusion didn't compute the subsurface properly so that's why theres the weird red and blue_

Now: Dual case time.

The way I handled this was pretty interesting: I duplicated the fusion project, and just went through the timeline step-by-step, updating to mirror things as needed.

First: the sketches

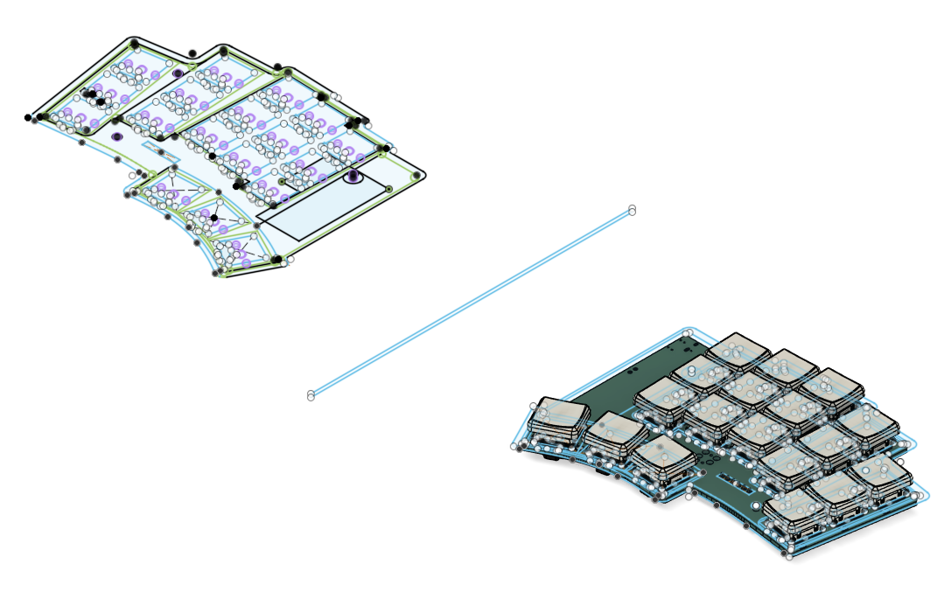
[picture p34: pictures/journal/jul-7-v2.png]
Revision 2 of the double case

_Also featuring a new PCB model!_

A not so fun part was, once again, the hotswap sockets, since they're only mirrored in pcb-space, but individually aren't. This lead to me having to adjust all of them by hand. Fun

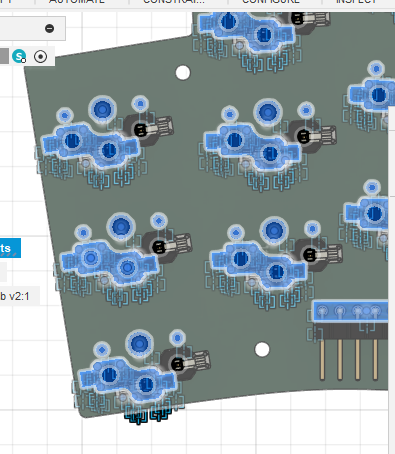
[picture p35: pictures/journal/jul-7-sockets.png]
Hotswap sockets facing the wrong way

_This was a pain to fix. Blegh_

Eventually, I finally got the sketches to a usable state. They went through about 20 more edits after this, but that was figuring out weird bugs and trying to improve tolerances.

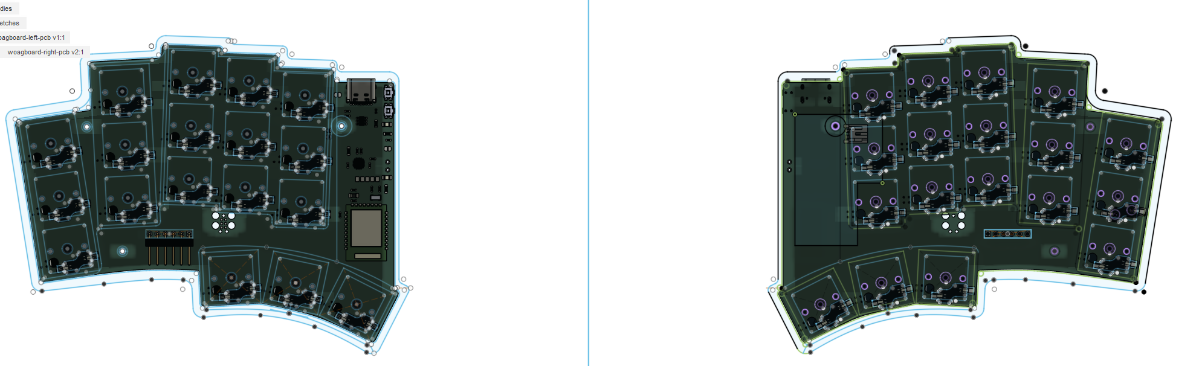
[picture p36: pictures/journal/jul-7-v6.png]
Revision 6 of the double case sketch

_LGTM_

**Total hours spent: 4 hours** (There was a _lot_ of adjusting to the sketches to make them more usable to work with.)

## July 8th+9th

I got a lot of work done on the dual case, to the point of near completion. There's about 5 more revisions of just sketch adjustments, which doesn't look that great on it's own, so I'll skip a bunch to where I actually have something worth showing:

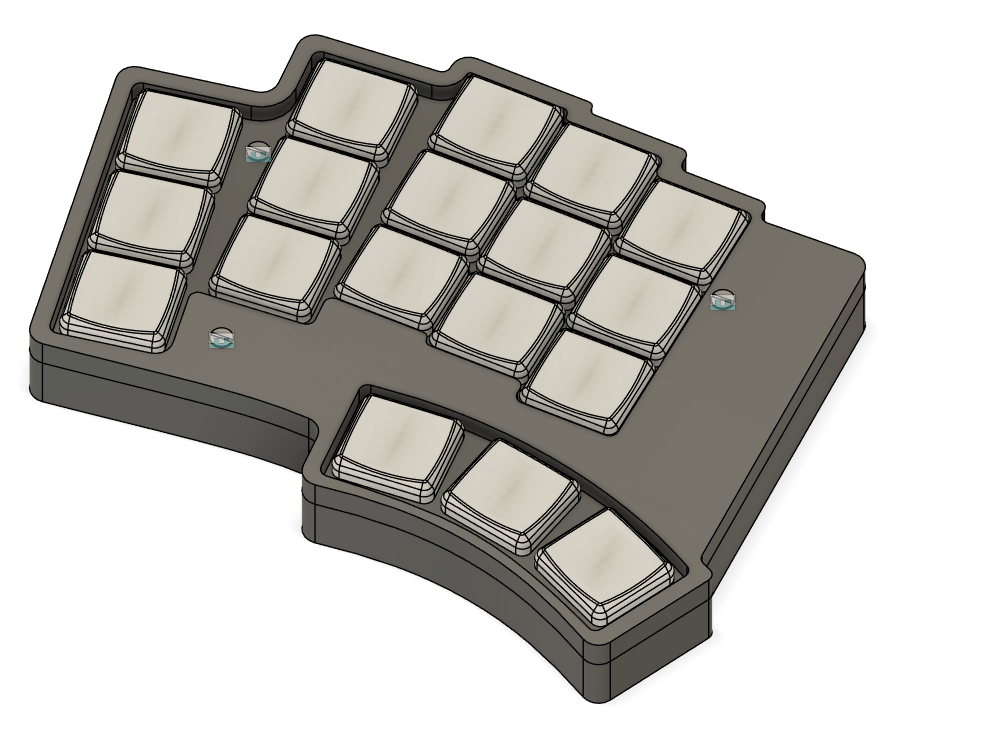
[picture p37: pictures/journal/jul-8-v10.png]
Revision 10 of the double case, left side only

_Screws!! And updated rounded corners, margins, tolerances, bevels..._

Turns out: screw selection is hard. I spent about 1 hour alone going between screw datasheets, sizing, and websites to try find one that works and looks good. I eventually settled on M2x10mm and M2x12mm DIN 963 screws for the reference design, but in reality, any countersunk M2 screw will work. Fusions screw tool is really nice, as it can just create screws on-the-fly and fit em in properly. It's nifty.

Another thing that's difficult is to get rounded corners to look nice. I'm trying to strike a balance between flow and style (that doesn't make much sense, but it does to my brain). This was pretty difficult since I'm bad at design (and this is the 2nd case I've worked on ever).

Also, you'll notice a small issue with this design: the thumb cluster is unusable. The case intersects _with your thumb._ Oops. I noticed this by revision 12 and fixed it.

Revision 13 of the dual case
_Your thumbs can now hit the keys without having to phase through the board or move your entire hand. Incredible._

Anyways, back to actual updates: I wanted to add tenting feet to my design, since the boards aggressive splay with the ring and pinky fingers are only super comfy when it's tented. The first few iterations had... Issues. Mainly: the feet intersected with screws and the USB port... oops

Cutout for tenting feet, showing an exposed screw and USB C port
_Ruh roh_

You also can see that the bottom case is uh... Thin. More specifically, .2mm. That ain't holding up. I fixed both of those in future revisions. Fast forward to the end of the day: we have something usable. Now it just needs polish.

Revision 18 of the dual case

**Total hours spent: 5 hours**

# July 13th

Back from holiday. Time to finish up this project. First up: the screen. I plan to use a nice!view, as mentioned earlier. Just need a way to mount it. I'm thinking maybe placing the screen in, and just covering with a sheet of plastic/acrylic that slides into the case. This should keep it removable as well.

The nice!view cutout
_niceeeeeeeeeeeeeeeeeeeeeeeeeee_

Materials in fusion 360 are weird. It took me a solid like 10 minutes to get the nice!view thing looking like that lol.

I also hollowed out the top half of the right side. This allows me to fit a battery in there, rather than having to put it with the components.

Battery compartment
_Hopefully this is enough space._

Also, as the last bit: holes for the buttons. I'm not going to be pressing them too often, so I won't add a bit that makes them easier to press for now. Probably will model something later

Holes for buttons
_Hole in two (I am running out of ideas for these)_

And with that, I think I'm done with the case! I'll probably be going through a lot more, but I think it's time to finalise my PCB BOM, do some final checks, and create a first draft of the firmware.

## RMK time

While going over the central.rs file for the firmware, I noticed there is an is_charging pin. I should probably use that. Lemme add it to the design lol

The new CHG trace to the MCU
_Also took the time to cleanup nearby traces_

And... RMK with just raw rust is hard. There's a _lot_ it handles for you with the keyboard.toml file, but at the same time, I do like the absolute typesafety and errors rust gives me. Also autocompletion. Mainly autocompletion.

I have had to deal with ~20 errors and a bunch of refactorings due to the way I made my board, but I eventually got it to work. Keymap porting took a long time though. There's also some weird cumbersome issues when using rust directly, but it's manageable.

I also had the side-quest of a VIAL layout, which I could autogenerate using [ergogen](https://github.com/ergogen/ergogen) and [kbplacer](https://github.com/adamws/kicad-kbplacer). Main issue: YAML nonsense

```YAML
      rows:
        bottom:
          row_net: 2
          mirror.row_net: 2
        home:
          row_net: 1
          mirror.row_net: 1
        top:
          row_net: 0
          mirror.row_net: 0
```

The row nets for the top row aren't exported. Why? YAML seemingly takes that 0 as false, and just yeets the field entirely. Thus, I had to quote it
```YAML
      rows:
        bottom:
          row_net: 2
          mirror.row_net: 2
        home:
          row_net: 1
          mirror.row_net: 1
        top:
          row_net: "0"
          mirror.row_net: "0"
```

And now, we have VIAL :yay:.

Screenshot of VIAL
_Configurable, even after flashed. Nice._

Anyways, I've spent most of the RMK work today going through the docs, figuring out everything at my disposal. I am missing a lot of stuff from ZMK:
- Tap Dance
- Auto Layers
- Per-key configuration for tap/layer holds

This probably makes this firmware less usable than my eventual ZMK option, but oh well /shrug. I have 1 layer down in code. Time for the rest of them tomorrow

**Total hours spent: 6 hours**

# July 14th

Finished RMK firmware dev, porting over from my zmk config. To make life easier for me in the future, I made a couple PRs to RMK! The main one is https://github.com/HaoboGu/rmk/pull/472, which makes some bits of the rust code (mostly Forks) a lot nicer to write.

Also: I went extra fancy on the formatting for fun
```rs
    #[rustfmt::skip]
    let base =
        [
        //  ╭─────────────┬─────────────┬─────────────┬─────────────┬─────────────╮ ╭─────────────┬─────────────┬─────────────┬─────────────┬─────────────╮
            [    k!(X),       k!(F),        k!(D),        k!(P),        k!(Q),           k!(J),      k!(Quote),      k!(O),        k!(U),       k!(Dot)   ],
        //  ├─────────────┼─────────────┼─────────────┼─────────────┼─────────────┤ ├─────────────┼─────────────┼─────────────┼─────────────┼─────────────┤
            [ mt!(N,ctrl), mt!(S,shift),  mt!(T,alt),   mt!(C,gui),     k!(Y),           k!(M),     mt!(H,gui),   mt!(A,alt),  mt!(E,shift),  mt!(I,ctrl) ],
        //  ├─────────────┼─────────────┼─────────────┼─────────────┼─────────────┤ ├─────────────┼─────────────┼─────────────┼─────────────┼─────────────┤
            [    k!(B),       k!(V),        k!(K),        k!(G),        k!(W),           k!(Z),        k!(L),    k!(RepeatKey),  k!(Slash),    k!(Comma)  ],
        //  ╰─────────────┴─────────────┼─────────────┼─────────────┼─────────────┤ ├─────────────┼─────────────┼─────────────├─────────────┴─────────────╯
            [a!(No),      a!(No),          k!(LGui),      k!(R),     lt!(fn,Return),    mo!(num),  lt!(nav,Space), k!(RShift),    a!(No),       a!(No)    ]
        //                              ╰─────────────┴─────────────┴─────────────╯ ╰─────────────┴─────────────┴─────────────╯
        ];
```

Can't really show images with code so none for today :pensive:

Tomorrow: Final work on the case and preparing to ship

**Total hours spent: 3 hours**

# July 15th

So, JLCPCB used to assemble the microcontroller I'm using (Ebyte E732G4M08S1C) on economic assembly. That for some reason changed. Hell. My PCBA costs went from $60 to $100. I've asked support on exactly why this happened. Looks like I'll need to change my other suppliers to cover the costs. Speaking of which, I added a BOM to my README.

BOM
_:b:ill of materials_

Due to the new costs from JLCPCB, I probably will have to pay for some of the stuff myself, which is just. Ugh.

Anyways, to distract myself from this annoyance, I decided to absolutely go ham on the silkscreen. There are now way too many references, memes, and just silly stuff. As it should be.

Silkscreen chaos
_WOAG_

**Total hours spent: 3 hours**

# July 16th

I finally got the JLCPCB support response. It wasn't that helpful. Weh. My best guess is a reliability issue. Guess I gotta pay extra sob.

Picture of JLCPCB quote for the board
_The budget eater (nom)_

Due to this, I'm not getting the nice!view. I just don't have the budget for it. I will probably add it later, but for now, I just wanna finish this project sob. I've also resorted to using AliExpress for some of the components, since typeractive + shipping
would just be too expensive.

I've also been hard at work in blender to make renders. It's honestly pretty fun.

Woagboard with the case opened
Woagboard Case
_More in the README file_

I also added a new firmware for the zmk under [woagboard-zmk](https://github.com/Suya1671/woagboard-zmk). This is an updated version of the old woagboard v0.2 firmware, but with the new layout and matrix.

**Total hours spent: 3 hours (4 hours if you include rendering lol)**

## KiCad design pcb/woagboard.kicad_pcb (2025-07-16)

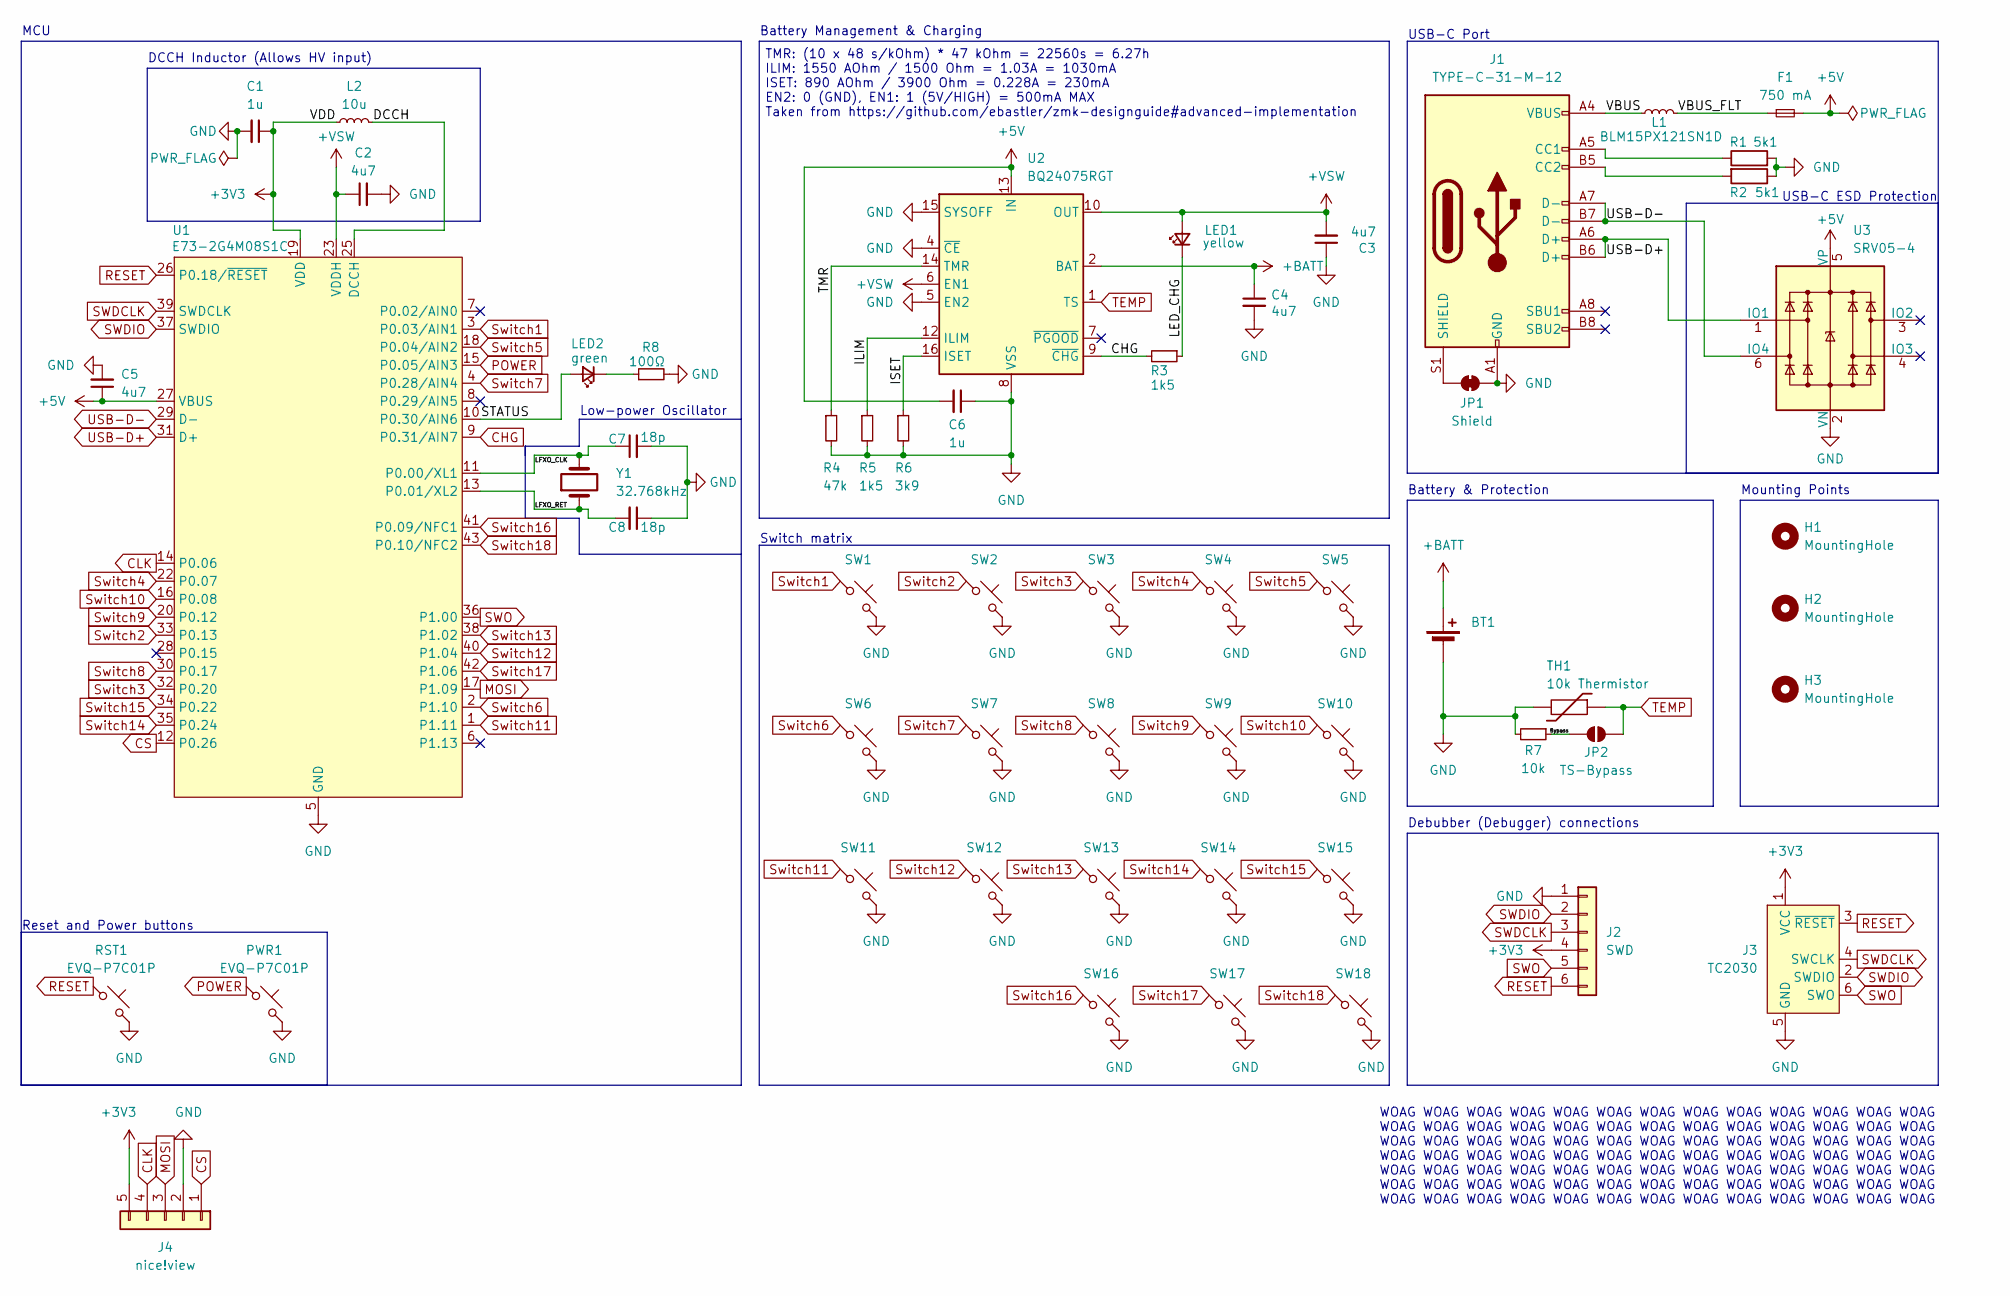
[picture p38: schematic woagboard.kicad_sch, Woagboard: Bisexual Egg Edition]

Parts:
BT1: Battery_Cell; JST_PH_S2B-PH-K_1x02_P2.00mm_Horizontal
C1, C6: 1u; C_0402_1005Metric_Pad0.74x0.62mm_HandSolder; LCSC C52923
C2, C3, C4, C5: 4u7; C_0402_1005Metric_Pad0.74x0.62mm_HandSolder; LCSC C23733
C7, C8: 18p; C_0402_1005Metric_Pad0.74x0.62mm_HandSolder; LCSC C1549
F1: 750 mA; Fuse_0603_1608Metric; LCSC C2687878
H1, H2, H3: MountingHole; MountingHole_2.2mm_M2
J1: TYPE-C-31-M-12; USB_C_Receptacle_HRO_TYPE-C-31-M-12; LCSC C165948
J2: SWD; PinHeader_1x06_P2.54mm_Horizontal; LCSC C706869
J3: TC2030; Tag-Connect_TC2030-IDC-FP_2x03_P1.27mm_Vertical
J4: nice!view; nice!view_pads
JP1: Shield; SolderJumper-2_P1.3mm_Bridged_RoundedPad1.0x1.5mm
JP2: TS-Bypass; SolderJumper-2_P1.3mm_Open_RoundedPad1.0x1.5mm
L1: BLM15PX121SN1D; L_0402_1005Metric; LCSC C88970
L2: 10u; L_0805_2012Metric_Pad1.15x1.40mm_HandSolder; LCSC C223249
LED1: yellow; LED_0805_2012Metric_Pad1.15x1.40mm_HandSolder; LCSC C2296
LED2: green; LED_0805_2012Metric_Pad1.15x1.40mm_HandSolder; LCSC C2297
PWR1: EVQ-P7C01P; LCSC C388883
R1, R2: 5k1; R_0402_1005Metric_Pad0.72x0.64mm_HandSolder; LCSC C25905
R3: 1k5; R_0603_1608Metric_Pad0.98x0.95mm_HandSolder; LCSC C25867
R4: 47k; R_0402_1005Metric_Pad0.72x0.64mm_HandSolder; LCSC C25792
R5: 1k5; R_0402_1005Metric_Pad0.72x0.64mm_HandSolder; LCSC C25867
R6: 3k9; R_0603_1608Metric_Pad0.98x0.95mm_HandSolder; LCSC C23018
R7: 10k; R_0402_1005Metric_Pad0.72x0.64mm_HandSolder; LCSC C25744
R8: 100Ω; R_0603_1608Metric_Pad0.98x0.95mm_HandSolder; LCSC C25867
RST1: EVQ-P7C01P; LCSC C388883
SW1, SW2, SW3, SW4, SW5, SW6, SW7, SW8, SW9, SW10, SW11, SW12, SW13, SW14, SW15, SW16, SW17, SW18: SW_Push_45deg; Choc-V1-HS-Reversible
TH1: 10k Thermistor; TestPoint_2Pads_Pitch2.54mm_Drill0.8mm
U1: E73-2G4M08S1C; nRF52840_E73-2G4M08S1C; LCSC C356849
U2: BQ24075RGT; QFN-16-1EP_3x3mm_P0.5mm_EP1.7x1.7mm; LCSC C15464
U3: SRV05-4; SOT-23-6-routable; LCSC C2836319
Y1: 32.768kHz; Q13FC13500004; LCSC C32346

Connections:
+3V3: C1.1, J2.4, J3.1 (VCC), J4.5, L2.1, U1.19 (VDD)
+5V: C5.1, C6.2, F1.2, U1.27 (VBUS), U2.13 (IN), U3.5 (VP)
+BATT: BT1.1 (+), C4.1, U2.2 (BAT), U2.3 (BAT)
+VSW: C2.1, C3.2, LED1.2 (A), U1.23 (VDDH), U2.6 (EN1), U2.10 (OUT), U2.11 (OUT)
/Bypass: JP2.1 (A), R7.1
/DCCH: L2.2, U1.25 (DCCH)
/ILIM: R5.1, U2.12 (ILIM)
/ISET: R6.1, U2.16 (ISET)
/LED_CHG: LED1.1 (K), R3.1
/LFXO_CLK: C7.1, U1.11 (P0.00/XL1), Y1.2
/LFXO_RET: C8.2, U1.13 (P0.01/XL2), Y1.1
/STATUS: LED2.2 (A), U1.10 (P0.30/AIN6)
/TMR: R4.1, U2.14 (TMR)
/VBUS: J1.A4 (VBUS), J1.A9 (VBUS), J1.B4 (VBUS), J1.B9 (VBUS), L1.1
/VBUS_FLT: F1.1, L1.2
CHG: R3.2, U1.9 (P0.31/AIN7), U2.9 (~CHG)
CLK: J4.4, U1.14 (P0.06)
CS: J4.1, U1.12 (P0.26)
GND: BT1.2 (-), C1.2, C2.2, C3.1, C4.2, C5.2, C6.1, C7.2, C8.1, J1.A1 (GND), J1.A12 (GND), J1.B1 (GND), J1.B12 (GND), J2.1, J3.5 (GND), J4.2, JP1.1 (A), PWR1.2, R1.2, R2.1, R4.2, R5.2, R6.2, R7.2, R8.2, RST1.2, SW1.2, SW2.2, SW3.2, SW4.2, SW5.2, SW6.2, SW7.2, SW8.2, SW9.2, SW10.2, SW11.2, SW12.2, SW13.2, SW14.2, SW15.2, SW16.2, SW17.2, SW18.2, TH1.2, U1.5 (GND), U1.21 (GND), U1.24 (GND), U2.4 (~CE), U2.5 (EN2), U2.8 (VSS), U2.15 (SYSOFF), U2.17 (VSS), U3.2 (VN)
MOSI: J4.3, U1.17 (P1.09)
unnamed: J1.A5 (CC1), R1.1
unnamed: J1.B5 (CC2), R2.2
unnamed: J1.S1 (SHIELD), JP1.2 (B)
unnamed: LED2.1 (K), R8.1
POWER: PWR1.1, U1.15 (P0.05/AIN3)
RESET: J2.6, J3.3 (~RESET), RST1.1, U1.26 (P0.18/~RESET)
SWDCLK: J2.3, J3.4 (SWCLK), U1.39 (SWDCLK)
SWDIO: J2.2, J3.2 (SWDIO), U1.37 (SWDIO)
SWO: J2.5, J3.6 (SWO), U1.36 (P1.00)
Switch1: SW1.1, U1.3 (P0.03/AIN1)
Switch2: SW2.1, U1.33 (P0.13)
Switch3: SW3.1, U1.32 (P0.20)
Switch4: SW4.1, U1.22 (P0.07)
Switch5: SW5.1, U1.18 (P0.04/AIN2)
Switch6: SW6.1, U1.2 (P1.10)
Switch7: SW7.1, U1.4 (P0.28/AIN4)
Switch8: SW8.1, U1.30 (P0.17)
Switch9: SW9.1, U1.20 (P0.12)
Switch10: SW10.1, U1.16 (P0.08)
Switch11: SW11.1, U1.1 (P1.11)
Switch12: SW12.1, U1.40 (P1.04)
Switch13: SW13.1, U1.38 (P1.02)
Switch14: SW14.1, U1.35 (P0.24)
Switch15: SW15.1, U1.34 (P0.22)
Switch16: SW16.1, U1.41 (P0.09/NFC1)
Switch17: SW17.1, U1.42 (P1.06)
Switch18: SW18.1, U1.43 (P0.10/NFC2)
TEMP: JP2.2 (B), TH1.1, U2.1 (TS)
USB-D+: J1.A6 (D+), J1.B6 (D+), U1.31 (D+), U3.1 (IO1)
USB-D-: J1.A7 (D-), J1.B7 (D-), U1.29 (D-), U3.6 (IO4)

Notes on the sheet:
WOAG WOAG WOAG WOAG WOAG WOAG WOAG WOAG WOAG WOAG WOAG WOAG WOAG WOAG WOAG WOAG WOAG WOAG WOAG WOAG WOAG WOAG WOAG WOAG WOAG WOAG WOAG WOAG WOAG WOAG WOAG WOAG WOAG WOAG WOAG WOAG WOAG WOAG WOAG WOAG WOAG WOAG WOAG WOAG WOAG WOAG WOAG WOAG WOAG WOAG WOAG WOAG WOAG WOAG WOAG WOAG WOAG WOAG WOAG WOAG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
DCCH Inductor (Allows HV input)
Mounting Points
Debubber (Debugger) connections
Battery & Protection
USB-C ESD Protection
Switch matrix
USB-C Port
Low-power Oscillator
MCU
TMR: (10 x 48 s/kOhm) * 47 kOhm = 22560s = 6.27h ILIM: 1550 AOhm / 1500 Ohm = 1.03A = 1030mA ISET: 890 AOhm / 3900 Ohm = 0.228A = 230mA EN2: 0 (GND), EN1: 1 (5V/HIGH) = 500mA MAX Taken from https://github.com/ebastler/zmk-designguide#advanced-implementation
Battery Management & Charging
Reset and Power buttons

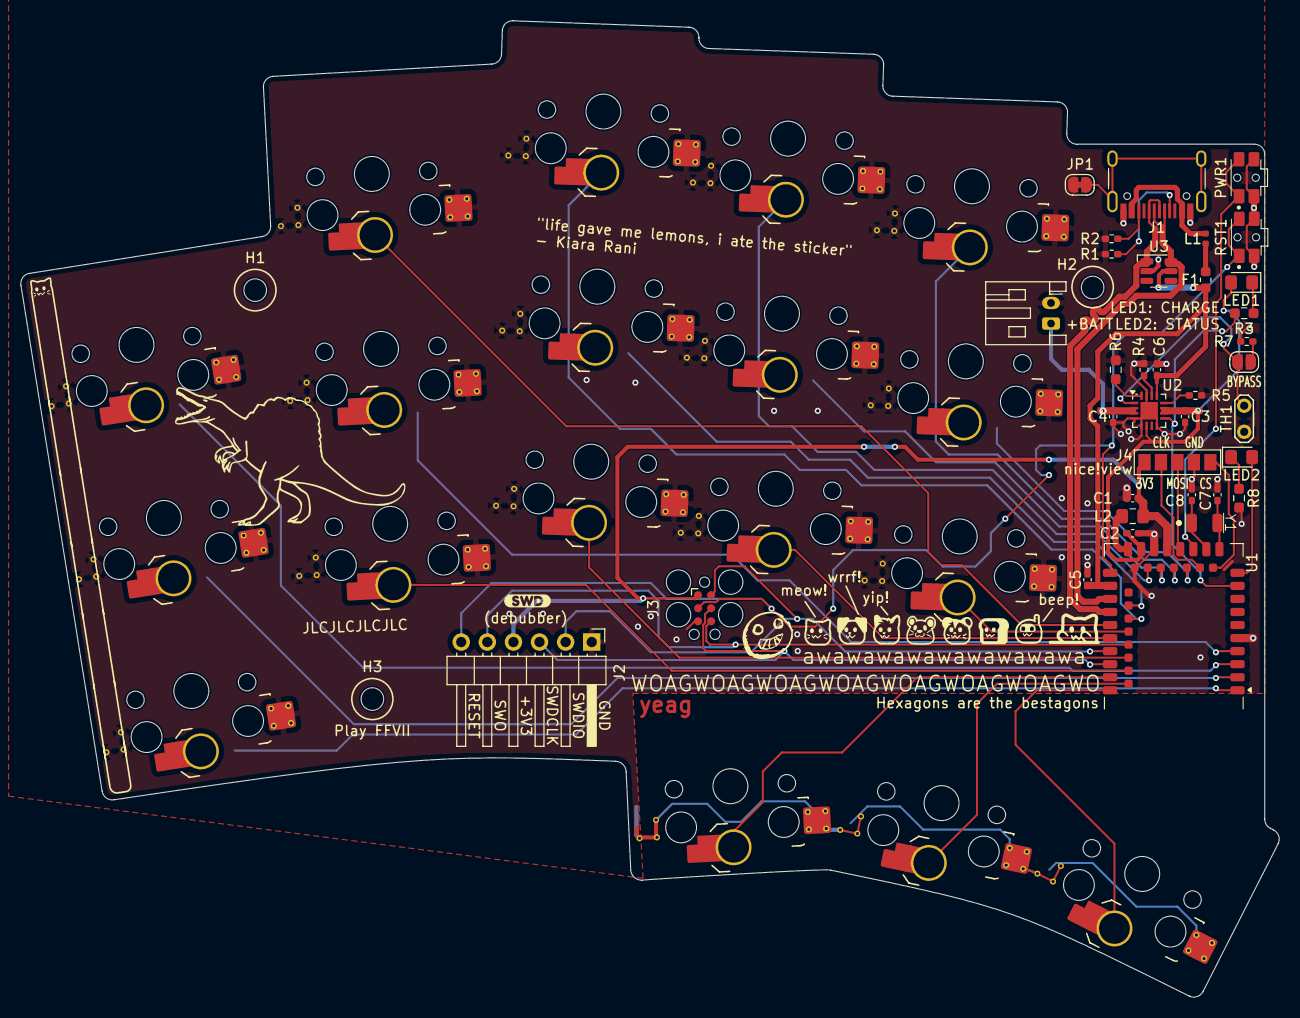
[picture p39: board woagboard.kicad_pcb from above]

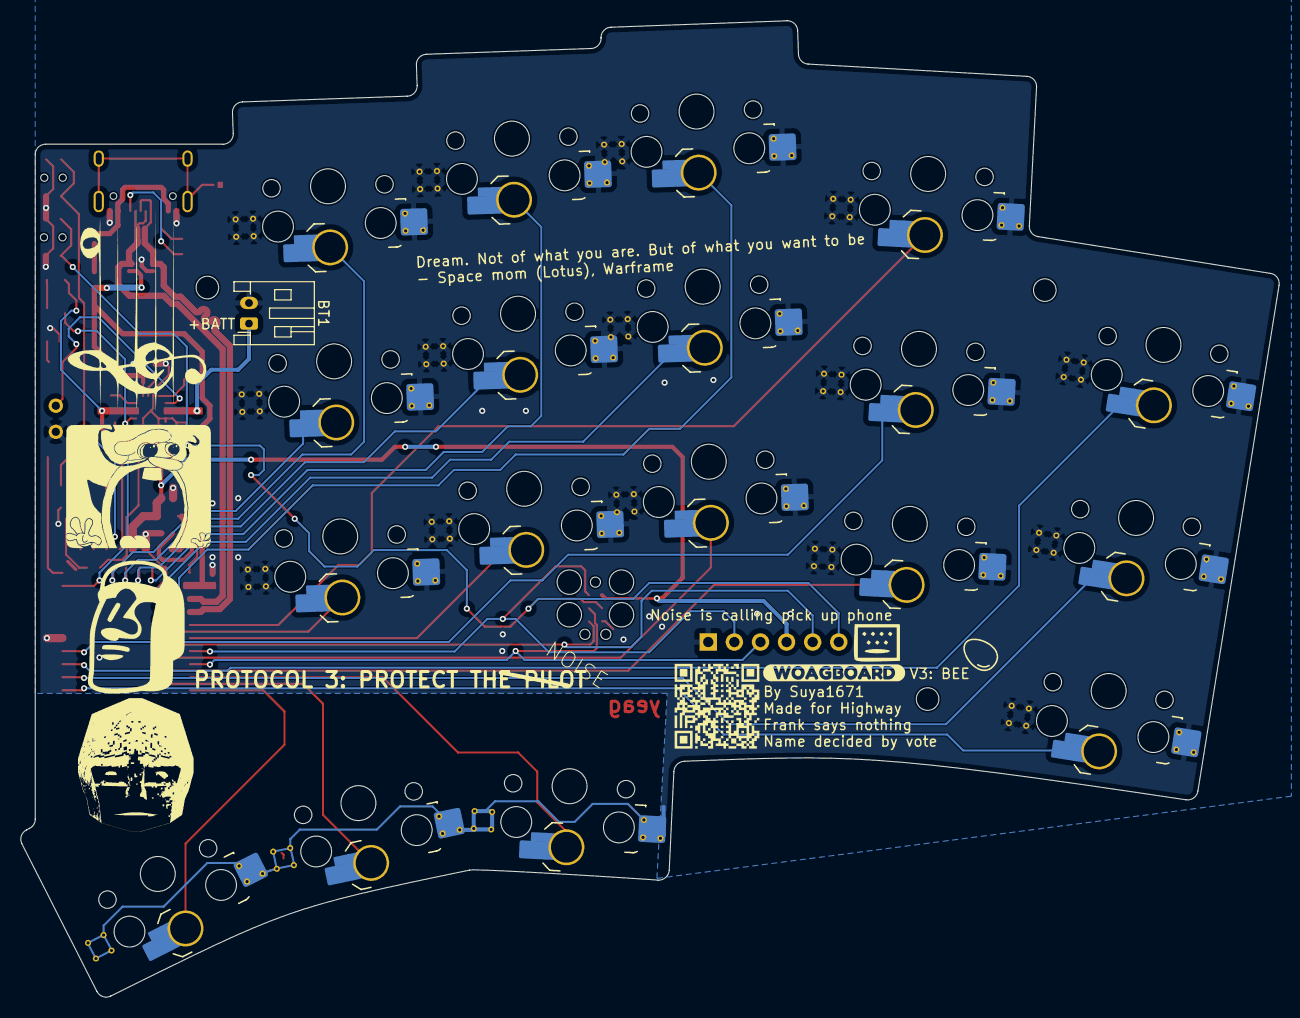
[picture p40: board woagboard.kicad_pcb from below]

Board: 2 copper layers, 122.5 x 95.0 mm, 59 parts (3 on the bottom side), 50 nets.

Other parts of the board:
QR*****: WobblQR
kibuzzard-686125E5: G***; kibuzzard-686125E5
kibuzzard-686573C8: G***; kibuzzard-686573C8

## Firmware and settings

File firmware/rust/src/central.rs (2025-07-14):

#![no_std]
#![no_main]

mod keymap;
#[macro_use]
mod macros;
mod common;
mod vial;

use common::{ble_addr, init_adc, mpsl_task, COL, L2CAP_MTU, ROW, SIZE};
use defmt::{info, unwrap};
use embassy_executor::Spawner;
use embassy_nrf::{
    bind_interrupts,
    gpio::{Input, Output},
    mode::Async,
    peripherals::{RNG, SAADC, USBD},
    rng,
    saadc::{self, Input as _},
    usb::{self, vbus_detect::HardwareVbusDetect, Driver},
};
use embassy_time::Duration;
use keymap::{get_combos, get_forks, NUM_LAYER};
use nrf_mpsl::Flash;
use nrf_sdc::{
    self as sdc,
    mpsl::{self, MultiprotocolServiceLayer},
};
use rand_chacha::ChaCha12Rng;
use rand_core::SeedableRng;
use rmk::{
    ble::trouble::build_ble_stack,
    channel::EVENT_CHANNEL,
    config::{
        BehaviorConfig, ControllerConfig, KeyboardUsbConfig, RmkConfig, StorageConfig,
        TapHoldConfig, VialConfig,
    },
    debounce::default_debouncer::DefaultDebouncer,
    futures::future::{join, join4},
    initialize_keymap_and_storage,
    input_device::{
        adc::{AnalogEventType, NrfAdc},
        battery::{BatteryProcessor, ChargingStateReader},
        Runnable,
    },
    keyboard::Keyboard,
    light::LightController,
    run_devices, run_processor_chain, run_rmk,
    split::{
        ble::central::read_peripheral_addresses,
        central::{run_peripheral_manager, CentralDirectPinMatrix},
    },
    HostResources,
};
use static_cell::StaticCell;
use vial::{VIAL_KEYBOARD_DEF, VIAL_KEYBOARD_ID};
use {defmt_rtt as _, panic_probe as _};

bind_interrupts!(struct Irqs {
    USBD => usb::InterruptHandler<USBD>;
    SAADC => saadc::InterruptHandler;
    RNG => rng::InterruptHandler<RNG>;
    EGU0_SWI0 => nrf_sdc::mpsl::LowPrioInterruptHandler;
    CLOCK_POWER => nrf_sdc::mpsl::ClockInterruptHandler, usb::vbus_detect::InterruptHandler;
    RADIO => nrf_sdc::mpsl::HighPrioInterruptHandler;
    TIMER0 => nrf_sdc::mpsl::HighPrioInterruptHandler;
    RTC0 => nrf_sdc::mpsl::HighPrioInterruptHandler;
});

/// How many outgoing L2CAP buffers per link
const L2CAP_TXQ: u8 = 4;

/// How many incoming L2CAP buffers per link
const L2CAP_RXQ: u8 = 4;

fn build_sdc<'d, const N: usize>(
    p: nrf_sdc::Peripherals<'d>,
    rng: &'d mut rng::Rng<RNG, Async>,
    mpsl: &'d MultiprotocolServiceLayer,
    mem: &'d mut sdc::Mem<N>,
) -> Result<nrf_sdc::SoftdeviceController<'d>, nrf_sdc::Error> {
    sdc::Builder::new()?
        .support_adv()?
        .support_scan()?
        .support_central()?
        .support_peripheral()?
        .support_dle_peripheral()?
        .support_dle_central()?
        .support_phy_update_central()?
        .support_phy_update_peripheral()?
        .support_le_2m_phy()?
        .central_count(1)?
        .peripheral_count(1)?
        .buffer_cfg(L2CAP_MTU, L2CAP_MTU, L2CAP_TXQ, L2CAP_RXQ)?
        .build(p, rng, mpsl, mem)
}

#[embassy_executor::main]
async fn main(spawner: Spawner) {
    info!("[WOAG CENTRAL] RMK Initialising");
    // Initialize the peripherals and nrf-sdc controller
    let mut nrf_config = embassy_nrf::config::Config::default();
    nrf_config.dcdc.reg0_voltage = Some(embassy_nrf::config::Reg0Voltage::_3V3);
    nrf_config.dcdc.reg0 = true;
    nrf_config.dcdc.reg1 = true;

    let p = embassy_nrf::init(nrf_config);

    let mpsl_p =
        mpsl::Peripherals::new(p.RTC0, p.TIMER0, p.TEMP, p.PPI_CH19, p.PPI_CH30, p.PPI_CH31);
    let lfclk_cfg = mpsl::raw::mpsl_clock_lfclk_cfg_t {
        source: mpsl::raw::MPSL_CLOCK_LF_SRC_RC as u8,
        rc_ctiv: mpsl::raw::MPSL_RECOMMENDED_RC_CTIV as u8,
        rc_temp_ctiv: mpsl::raw::MPSL_RECOMMENDED_RC_TEMP_CTIV as u8,
        accuracy_ppm: mpsl::raw::MPSL_DEFAULT_CLOCK_ACCURACY_PPM as u16,
        skip_wait_lfclk_started: mpsl::raw::MPSL_DEFAULT_SKIP_WAIT_LFCLK_STARTED != 0,
    };
    static MPSL: StaticCell<MultiprotocolServiceLayer> = StaticCell::new();
    static SESSION_MEM: StaticCell<mpsl::SessionMem<1>> = StaticCell::new();
    let mpsl = MPSL.init(unwrap!(mpsl::MultiprotocolServiceLayer::with_timeslots(
        mpsl_p,
        Irqs,
        lfclk_cfg,
        SESSION_MEM.init(mpsl::SessionMem::new())
    )));
    spawner.must_spawn(mpsl_task(&*mpsl));

    let sdc_p = sdc::Peripherals::new(
        p.PPI_CH17, p.PPI_CH18, p.PPI_CH20, p.PPI_CH21, p.PPI_CH22, p.PPI_CH23, p.PPI_CH24,
        p.PPI_CH25, p.PPI_CH26, p.PPI_CH27, p.PPI_CH28, p.PPI_CH29,
    );
    let mut rng = rng::Rng::new(p.RNG, Irqs);
    let mut rng_gen = ChaCha12Rng::from_rng(&mut rng).unwrap();
    let mut sdc_mem = sdc::Mem::<8192>::new();
    let sdc = unwrap!(build_sdc(sdc_p, &mut rng, mpsl, &mut sdc_mem));
    let mut host_resources = HostResources::new();
    let stack = build_ble_stack(sdc, ble_addr(), &mut rng_gen, &mut host_resources).await;

    // Initialize usb driver
    let driver = Driver::new(p.USBD, Irqs, HardwareVbusDetect::new(Irqs));

    // Initialize flash
    let flash = Flash::take(mpsl, p.NVMC);

    // Initialize IO Pins
    #[rustfmt::skip]
    let pins = config_matrix_pins!(
        peripherals: p,
        direct_pins: [
            [P0_03, P0_13, P0_20, P0_07, P0_04],
            [P1_10, P0_28, P0_17, P0_12, P0_08],
            [P1_11, P1_04, P1_02, P0_24, P0_22],
            [_, _, P0_09, P1_06, P0_10]
        ]
    );

    // Initialize the ADC.
    let adc_pin = saadc::VddhDiv5Input.degrade_saadc();
    let is_charging_pin = Input::new(p.P0_31, embassy_nrf::gpio::Pull::Up);
    let saadc = init_adc(adc_pin, p.SAADC);
    // Wait for ADC calibration.
    saadc.calibrate().await;

    // Keyboard config
    let keyboard_usb_config = KeyboardUsbConfig {
        vid: 0x4c4b,
        pid: 0x4643,
        manufacturer: "Suya Singh",
        product_name: "Woagboard",
        serial_number: "vial:f64c2b3c:000001",
    };
    let vial_config = VialConfig::new(VIAL_KEYBOARD_ID, VIAL_KEYBOARD_DEF);
    let mut charging_state_reader = ChargingStateReader::new(is_charging_pin, true);
    let storage_config = StorageConfig {
        start_addr: 0xA0000,
        num_sectors: 6,
        ..Default::default()
    };
    let rmk_config = RmkConfig {
        usb_config: keyboard_usb_config,
        vial_config,
        storage_config,
        ..Default::default()
    };

    // Initialze keyboard stuffs
    // Initialize the storage and keymap
    let mut default_keymap = keymap::get_default_keymap();
    let behavior_config = BehaviorConfig {
        tap_hold: TapHoldConfig {
            enable_hrm: true,
            permissive_hold: true,
            chordal_hold: true,
            prior_idle_time: Duration::from_millis(150),
            ..Default::default()
        },
        fork: get_forks(),
        combo: get_combos(),
        ..Default::default()
    };
    let (keymap, mut storage) =
        initialize_keymap_and_storage(&mut default_keymap, flash, &storage_config, behavior_config)
            .await;

    // Initialize the matrix and keyboard
    let debouncer = DefaultDebouncer::<4, 7>::new();
    let mut matrix =
        CentralDirectPinMatrix::<_, _, 0, 0, ROW, COL, SIZE>::new(pins, debouncer, true);
    // let mut matrix = TestMatrix::<ROW, COL>::new();
    let mut keyboard = Keyboard::new(&keymap);

    // Read peripheral address from storage
    let peripheral_addrs =
        read_peripheral_addresses::<1, _, ROW, { COL * 2 }, NUM_LAYER, 0>(&mut storage).await;

    // Initialize the light controller
    let mut light_controller: LightController<Output> =
        LightController::new(ControllerConfig::default().light_config);

    let mut adc_device = NrfAdc::new(
        saadc,
        [AnalogEventType::Battery],
        embassy_time::Duration::from_secs(12),
        None,
    );
    let mut batt_proc = BatteryProcessor::new(2000, 2806, &keymap);

    // Start
    join4(
        run_devices! (
            (matrix, adc_device, charging_state_reader) => EVENT_CHANNEL,
        ),
        run_processor_chain! {
            EVENT_CHANNEL => [batt_proc],
        },
        keyboard.run(),
        join(
            run_peripheral_manager::<ROW, COL, 4, 0, _>(0, peripheral_addrs[0], &stack),
            run_rmk(
                &keymap,
                driver,
                &stack,
                &mut storage,
                &mut light_controller,
                rmk_config,
            ),
        ),
    )
    .await;
}

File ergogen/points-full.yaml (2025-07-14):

matrix_pinky_bottom:
  x: 0
  'y': 0
  r: 9
  meta:
    stagger: 0
    spread: 18
    splay: 0
    origin:
      - 0
      - 0
    orient: 0
    shift:
      - 0
      - 0
    rotate: 0
    width: 18
    height: 17
    padding: 17
    autobind: 10
    skip: false
    asym: both
    colrow: pinky_bottom
    name: matrix_pinky_bottom
    column_net: '0'
    mirror:
      column_net: 9
      row_net: 2
    row_net: 2
    zone: &ref_1
      key:
        padding: 1ky
        spread: 1kx
        splay: -10
      columns:
        pinky: &ref_0
          key:
            splay: 0
            stagger: pinky_stagger
            spread: pinky_spread
            column_net: '0'
            mirror:
              column_net: 9
          rows: {}
          name: pinky
        ring: &ref_2
          key:
            splay: ring_splay - pinky_splay
            stagger: ring_stagger
            spread: ring_spread
            column_net: 1
            mirror:
              column_net: 8
          rows: {}
          name: ring
        middle: &ref_3
          key:
            splay: middle_splay - ring_splay
            stagger: middle_stagger
            spread: middle_spread
            column_net: 2
            mirror:
              column_net: 7
          rows: {}
          name: middle
        index: &ref_4
          key:
            splay: index_splay - middle_splay
            stagger: index_stagger
            spread: index_spread
            column_net: 3
            mirror:
              column_net: 6
          rows: {}
          name: index
        inner: &ref_5
          key:
            splay: inner_splay - middle_splay
            stagger: inner_stagger
            spread: inner_spread
            column_net: 4
            mirror:
              column_net: 5
          rows: {}
          name: inner
      rows:
        bottom:
          row_net: 2
          mirror:
            row_net: 2
        home:
          row_net: 1
          mirror:
            row_net: 1
        top:
          row_net: '0'
          mirror:
            row_net: '0'
      name: matrix
    col: *ref_0
    row: bottom
    bind:
      - 10
      - 0
      - 0
      - 0
    mirrored: false
matrix_pinky_home:
  x: -2.6593859
  'y': 16.7907018
  r: 9
  meta:
    stagger: 0
    spread: 18
    splay: 0
    origin:
      - 0
      - 0
    orient: 0
    shift:
      - 0
      - 0
    rotate: 0
    width: 18
    height: 17
    padding: 17
    autobind: 10
    skip: false
    asym: both
    colrow: pinky_home
    name: matrix_pinky_home
    column_net: '0'
    mirror:
      column_net: 9
      row_net: 1
    row_net: 1
    zone: *ref_1
    col: *ref_0
    row: home
    bind:
      - 10
      - 10
      - 10
      - 0
    mirrored: false
matrix_pinky_top:
  x: -5.3187718
  'y': 33.5814036
  r: 9
  meta:
    stagger: 0
    spread: 18
    splay: 0
    origin:
      - 0
      - 0
    orient: 0
    shift:
      - 0
      - 0
    rotate: 0
    width: 18
    height: 17
    padding: 17
    autobind: 10
    skip: false
    asym: both
    colrow: pinky_top
    name: matrix_pinky_top
    column_net: '0'
    mirror:
      column_net: 9
      row_net: '0'
    row_net: '0'
    zone: *ref_1
    col: *ref_0
    row: top
    bind:
      - 0
      - 10
      - 10
      - 0
    mirrored: false
matrix_ring_bottom:
  x: 19.3004201
  'y': 16.2189329
  r: 3
  meta:
    stagger: 13
    spread: 21.599999999999998
    splay: -6
    origin:
      - 0
      - 0
    orient: 0
    shift:
      - 0
      - 0
    rotate: 0
    width: 18
    height: 17
    padding: 17
    autobind: 10
    skip: false
    asym: both
    colrow: ring_bottom
    name: matrix_ring_bottom
    column_net: 1
    mirror:
      column_net: 8
      row_net: 2
    row_net: 2
    zone: *ref_1
    col: *ref_2
    row: bottom
    bind:
      - 10
      - 0
      - 0
      - 10
    mirrored: false
matrix_ring_home:
  x: 18.410708800000002
  'y': 33.195634999999996
  r: 3
  meta:
    stagger: 13
    spread: 21.599999999999998
    splay: -6
    origin:
      - 0
      - 0
    orient: 0
    shift:
      - 0
      - 0
    rotate: 0
    width: 18
    height: 17
    padding: 17
    autobind: 10
    skip: false
    asym: both
    colrow: ring_home
    name: matrix_ring_home
    column_net: 1
    mirror:
      column_net: 8
      row_net: 1
    row_net: 1
    zone: *ref_1
    col: *ref_2
    row: home
    bind:
      - 10
      - 10
      - 10
      - 10
    mirrored: false
matrix_ring_top:
  x: 17.520997500000004
  'y': 50.17233709999999
  r: 3
  meta:
    stagger: 13
    spread: 21.599999999999998
    splay: -6
    origin:
      - 0
      - 0
    orient: 0
    shift:
      - 0
      - 0
    rotate: 0
    width: 18
    height: 17
    padding: 17
    autobind: 10
    skip: false
    asym: both
    colrow: ring_top
    name: matrix_ring_top
    column_net: 1
    mirror:
      column_net: 8
      row_net: '0'
    row_net: '0'
    zone: *ref_1
    col: *ref_2
    row: top
    bind:
      - 0
      - 10
      - 10
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

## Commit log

2024-09-07 feat: inital yaml file for the woagboard and removed unneeded kicad schematics
    [designguide-schematic.kicad_pcb, designguide-schematic.kicad_sch, woagboard.kicad_pcb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]
2024-09-08 pcb: start working on pcb design
    [matrix.kicad_sch, woagboard.kicad_pcb, woagboard.kicad_sch]
2024-09-11 wip: finish left half and start work on right half
    [matrix.kicad_sch, woagboard.kicad_pcb, woagboard.kicad_sch]
2024-09-13 wip: initial pcb of full woagboard
    note: Do not print this. It's not even close to ready probably
    [BOM-woagboard.csv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]
2024-09-14 fix: much better routing
    [woagboard.kicad_pcb, woagboard.kicad_sch]
2024-09-15 pcb: more pcb design and silkscreen shenanigains
    [BOM-woagboard.csv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]
2024-09-16 chore: move some traces
    [woagboard.kicad_pcb]
2024-09-16 feat: better usb trace impedance and silkscreen shenangains
    [BOM-woagboard.csv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]
2024-09-17 chore: more silkscreen stuffs
    [woagboard.kicad_pcb]
2024-09-17 feat: RC1
    [woagboard.kicad_pcb, woagboard.kicad_sch]
2024-09-17 chore: generate manufacturing files
    [BOM-woagboard.csv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]
2024-09-17 pcb: replace oscillator
    [BOM-woagboard.csv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]
2024-09-23 wip(pcb): heavy wip on woagboard v0.2
    - new usb port
    - redoing routing again
    - soldering + hotswap in one
    [USBLC6-2SC6.step, woagboard.kicad_pcb, woagboard.kicad_sch]
2024-09-26 feat: woagboard V0.2 REV1
    [BOM-woagboard.csv, EVQ-P7C01P--3DModel-STEP-269445.STEP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]
2024-09-26 feat: better DCCH loop
    [CPL-woagboard.csv, woagboard-CuBottom.gbr, woagboard-CuTop.gbr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]
2024-09-27 feat: better grounding and positioning
    [BOM-woagboard.csv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]
2024-09-27 chore: remove vcut comment
    [woagboard-CuBottom.gbr, woagboard-CuTop.gbr, woagboard-EdgeCuts.gbr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]
2024-10-05 feat: add bootloader
    [woagboard.kicad_pcb]
2024-10-16 fix: fix the single biggest mistake on the board
    I blew up the left half because of this missing trace. No idea how to fix my current boards now....
    [woagboard.kicad_pcb, woagboard.kicad_sch]
2025-06-28 feat: yeet existing design and replace with modified yeagboard
    [BOM-woagboard.csv, EVQ-P7C01P--3DModel-STEP-269445.STEP, USBLC6-2SC6.step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]
2025-06-28 feat: add new pcb files
    [woagboard.kicad_pcb, woagboard.kicad_sch]
2025-06-29 feat: initial pcb
    [EVQP7C01P--3DModel-STEP-269445.STEP, Q13FC13500004.STEP, woagboard.kicad_pcb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]
2025-07-02 feat: reorganise and add basic case files
    [BQ24075.STEP, EVQP7C01P--3DModel-STEP-269445.STEP, Kailh LP Choc PC Keycap.step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]
2025-07-03 feat: add larger files
    [SW_Kailh_Choc_V1.stp, woagboard.kicad_pcb]
2025-07-13 feat: add case
    [Kailh LP Choc PC Keycap.step, MBK_Keycap_-_1u.step, woagboard.kicad_pcb]
2025-07-14 feat: add rust firmware
    [woagboard.kicad_pcb, woagboard.kicad_sch]
2025-07-15 feat: updated production files
    [BOM-woagboard.csv, BOM.csv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]
2025-07-15 feat: add silkscreen image
2025-07-15 chore; remove unnessesary * in BOM
    [BOM.csv]
2025-07-16 feat: add renders
    [BOM-woagboard.csv, BOM.csv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]
2025-07-16 feat: add in case stl files
    [Top Left.stl, Top Right.stl]
2025-07-25 chore: move production files to dedicated folter
    [BOM-woagboard.csv, Top Left.stl, Top Right.stl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]
